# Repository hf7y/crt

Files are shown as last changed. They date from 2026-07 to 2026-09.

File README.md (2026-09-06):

# crt

Landline handset + CRT monitor as a voice-driven front end for Claude Code,
autobooting on potato, a Raspberry Pi.

## Signal path

```
handset mic (TRRS) --> potato audio in --> whisper (dexter's container, VAD-segmented)
                                                    |
                                                    v
                                        tmux send-keys into `claude` pane
                                                    |
                                                    v
                                          Claude Code CLI on CRT (HDMI->RCA)

hookswitch (mechanical, printed) --> USB keyboard-encoder --> evdev listener
                                                                     |
                                              pause/resume the STT loop
```

## One-time setup (on the console)

```
./install.sh
sudo reboot
```

This installs whisper.cpp + a base.en model, Claude Code CLI, and configures
tty1 to auto-login and drop straight into `bin/crt-console.sh`, which opens a
tmux session: Claude Code in the main pane, `stt-feed.sh` listening in a
lower pane. After reboot, no keyboard interaction is needed to reach the
Claude Code prompt.

First boot: `claude` will need a one-time interactive login (network
required). Do that once before relying on unattended autoboot.

## Manual test (no reboot)

```
bash bin/crt-console.sh
```

## Audio capture troubleshooting

Getting the mic to work took several non-obvious fixes; if a fresh deploy
captures silence, check these in order:

1. **User must be in the `audio` group.** Without a desktop/logind seat (i.e.
   over SSH, or on a stripped console-only box), `/dev/snd/*` is only reachable
   via the `audio` group. `install.sh` adds the user; a re-login/reboot applies
   it. Symptom: `arecord -l` says "no soundcards found" though the kernel shows
   the card in `/proc/asound/cards`.

2. **Capture from the hardware device, not ALSA `default`.** `default` can be
   silently re-routed to a dead PulseAudio/PipeWire by leftover config
   drop-ins. `stt-feed.sh` uses `plughw:0,0` via `CRT_AUDIO_DEV` for this reason.

3. **VAD threshold.** A quiet capture path (speech RMS ~1%) never trips the
   default 3% silence gate; lower it with
   `CRT_VAD_THRESHOLD`. Symptom: `rec` runs forever
   on `utt_1` and never emits a `[stt-feed] ->` line. Verify capture works at
   all by recording directly and transcribing:
   ```
   arecord -D plughw:0,0 -f S16_LE -c1 -r16000 -d 5 /tmp/t.wav
   ~/whisper.cpp/build/bin/whisper-cli -m ~/whisper.cpp/models/ggml-base.en.bin -f /tmp/t.wav -nt -np
   ```

## Hookswitch (physical on/off)

The mechanical hookswitch is **not wired to any analog phone line** — no PBX,
so no relay. It's a plain logic-level contact, read via `CRT_HOOK_TRANSPORT`
(`evtest`, default, or `gpio`):

**`evtest`.** Wire the microswitch (via `cad/switch_mount.scad`) to a cheap
USB arcade-button/keyboard-encoder board, one key while closed.
```
evtest                       # find the encoder's device path and confirm the key it sends
export CRT_HOOK_DEVICE=/dev/input/by-id/usb-...-event-kbd
export CRT_HOOK_KEY=KEY_F13  # match whatever the encoder actually sends
```

**`gpio`.** Wire the switch straight to a Pi GPIO pin instead (HOOKSWITCH.md option 3):
```
export CRT_HOOK_TRANSPORT=gpio
export CRT_HOOK_GPIO_PIN=17          # BCM pin the switch is wired to
export CRT_HOOK_GPIO_ACTIVE_LOW=1    # 1: pull-up, switch-to-GND on-hook (default)
```

Add the exports to `.bash_profile` above the `crt autoboot` block (installer
leaves a marker). Autostart then opens a third pane running
`hookswitch-listen.sh`, which SIGSTOPs/SIGCONTs `stt-feed.sh` as the handset
is placed down / picked up.

## 3D-printed handset assembly (`cad/`)

Four parametric OpenSCAD parts, one assembly:

- `phone_saddle.scad` — cup the handset barrel rests in ("phone" contact piece)
- `hook_lever.scad` — see-saw lever; handset weight presses it onto the switch
- `switch_mount.scad` — bracket holding the microswitch under the lever
- `cradle.scad` — base body with pivot-pin bosses and switch mount pocket

**Edit `cad/params.scad` first** — measure your actual handset barrel
diameter and your microswitch's real dimensions/hole spacing; the shipped
values are generic placeholders, not measurements of your hardware.

Render all STLs:
```
./cad/export_stl.sh
```
Outputs to `cad/stl/`. Assemble with a steel pin/M4 bolt through the pivot
bosses, then screw the switch into `switch_mount.scad` and tune
`switch_mount_h` in `params.scad` until the lever fully depresses the
plunger only when the handset is resting (not lifted).

## Bare-metal deployment (e.g. Intel Compute Stick)

Everything in `bin/` and `install.sh` targets any Debian/Ubuntu machine, and
the console settled on a Raspberry Pi (potato) rather than a hypervisor guest.

**Confirmed target (2026-07-21): Debian 13.6, amd64.** `install.sh`'s
package list (`build-essential cmake git tmux sox alsa-utils curl
openscad evtest`) is all present in Debian 13's repos under those exact
names — nothing to substitute. If the actual stick's CPU turns out to be
more capable than a Celeron (amd64 covers a wide range), test `base.en`
before defaulting to `tiny.en` below; the tradeoff is real either way,
this isn't a hard requirement, just the safe assumption for the weakest
hardware this doc originally targeted.

**Barcode scanner needs no forwarding at all on a single-box deployment**
(2026-07-21, see `SCANNER.md`'s "compute-stick prep" section) — the whole
`dexter-scanner-forward.ps1` / NAT-forward / `crt-scanner-feed.py`-HTTP
bridge exists only because the VM path splits the scanner (on Windows)
from the console (in the guest). Bare metal has one machine: plug the
USB scanner directly into the stick, and `crt-book-console.py`'s stdin
path (already the primary scan path, `install.sh` wires nothing extra
for it) picks it up with zero network hop.

Differences from the VM path:

- **Whisper model**: `base.en` is too heavy for a Celeron in real time.
  Use the smaller/faster `tiny.en` instead:
  ```
  CRT_WHISPER_MODEL_NAME=tiny.en ./install.sh
  ```
  (`install.sh` downloads whichever model name you pass and wires
  `CRT_WHISPER_MODEL` automatically if it isn't the default `base.en`.)
  Expect a noticeable accuracy drop vs `base.en` — worth testing both if
  the stick can keep up with `base.en` at all before committing to `tiny.en`.
- **Audio input**: most compute sticks expose only HDMI audio out (or a
  single combo headphone/mic jack, sometimes output-only). Check
  `arecord -l` after boot — if there's no capture device, or capture is a
  garbled combo-jack signal, add a cheap USB audio adapter for the TRRS
  handset mic rather than relying on onboard audio in.
- **Video out**: HDMI is typically native on these sticks, so the same
  HDMI→RCA path to the CRT applies unchanged.
- **Everything else** (autologin, tmux wiring, hookswitch evdev listener,
  `crt-console.sh`) is identical — `install.sh` + reboot is the whole setup.
- **Finding it on the network** (2026-07-21): `install.sh` installs
  `avahi-daemon` and sets the hostname (`CRT_HOSTNAME`, default
  `crt-console`), so it's reachable as `crt-console.local` from any
  device on the same LAN segment — no static IP, no router config
  (mDNS/multicast, same mechanism that makes `dexter.local` work).
  Doesn't cross routers/VLANs, though — `crt-console.sh` also flashes
  the box's actual IP on the physical screen for a few seconds at boot
  (`CRT_IP_FLASH_SECS`, default 4, `0` to disable) as a fallback that
  works regardless of network topology.
- **First-boot setup, unattended**: `install.sh` now supports both
  editing its own `CONFIG` block at the top (WiFi SSID/password,
  hostname, Gemini key, Claude credentials path) and answering
  interactive prompts for the same values — including pasting a
  `.credentials.json` directly at the prompt to skip Claude Code's
  one-time login entirely. See that file's own header.

## Porting to native Windows later

The STT/tmux/Claude Code pieces (`bin/`) are Linux-specific (evdev, ALSA,
tmux). Porting means: swap `sox`/`rec` for a Windows-native audio capture,
swap `evtest`/evdev for a Windows raw-HID or keyboard-hook listener for the
hookswitch encoder, and replace tmux + autologin with a Windows Task
Scheduler entry running at logon that opens a terminal into the same
`claude` + STT-feed pair. The whisper.cpp binary and model are portable
as-is (Windows build exists upstream).

## Why this repo is public

Decided 2026-09-05 (hf7y/crt#148): public keeps Actions free for the images
dexter runs, and exposes topology only, never access. The `gitleaks` PR
check is what keeps that true by construction, not by care.

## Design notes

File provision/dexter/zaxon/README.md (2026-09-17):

# zaxon — crt's WhatsApp channel

**crt owns zaxon as of 2026-08-14 (Zach's call.)** An MCP server over
streamable-http exposing `ask_zach`, `revise_zach_question` and
`check_zach_reply`; loopback and tailnet only (#52). See `compose.yaml` for the
rest. One question per ticket, enforced at the send (crt#190) -- see the
`instructions=` string in `relay/zaxon_relay_server.py`.

Deploys are automatic — `srv-reconcile` (senechal-owned, dexter-wide, crt#322)
pulls and verifies `/srv/zaxon` on its own timer, rolling back on failure.
`zaxon-autoupdate.timer` did this job until crt#334 retired it, once
srv-reconcile covered zaxon too and running both risked a race. By hand:
`sudo docker compose pull && sudo docker compose up -d` (`sudo` because
`zach` is not in the `docker` group).

`data/` is service state, never overwritten from a repo; the relay's SOURCE ships in the image.

## The status page

`hf7y.com/zaxon` — `zaxon-watch.sh --apply` hourly, `--install` writes the timer,
`--check` publishes nothing. What used to be written down here as rules a reader
had to remember is enforced by `tests/test_zaxon_watch_guards.sh` and reported
by the page itself: the one-holder rule for `data/whatsapp/session` and
`data/auth.json` (crt#193, crt#195), the never-bind-`0.0.0.0` rule, where the
STT command lives, and why a relay that merely answers is never `OK`.

## Open

- `hermes` is still registered and can still seize the session (page reports it hourly); before `wsl --unregister hermes`, its verified `.vhdx`/`ggml-base.en.bin` export is at `/mnt/d/gardien-backups/hermes-wsl-export/` on dexter.
- **Opt-in shared-secret auth landed (crt#194)** — `relay/zaxon_relay_server.py`
  refuses any request missing the right `X-Zaxon-Shared-Secret` header once
  `ZAXON_SHARED_SECRET` is set, but ships unconfigured (a no-op, same as
  before) until dexter's own `provision/dexter/zaxon/.env` sets it. Still
  unauthenticated on the tailnet until that step happens.
- Stop the old stack before starting a new one against this same `data/`: two stacks holding one
  Nous refresh token revoked the session for 8 days (crt#193, 2026-08-30's migration overlap).

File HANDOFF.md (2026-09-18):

# crt — current state & handoff

Voice-driven secretary console: a landline handset + CRT TV as the human
interface. This doc is the pick-up-where-we-left-off summary — read this
first, then follow the pointers below for depth on any one piece.

**Read next, depending on what you're doing:**
- `README.md` — the how-and-why of each original piece, incl. detailed audio
  troubleshooting.
- `gh issue list -R hf7y/crt` — current backlog/status; the file backlog is retired.
- `SECRETARY.md` — the actual product vision (phone secretary, not a raw STT
  terminal) and what's built vs. still design-only.
- `AUDIO-DEBUG.md` — mic capture staleness debugging (5 parallel approaches).
- `vault:crt/AUDIO-ROUTING.md` — TV vs. phone-earpiece audio output separation.
- `vault:crt/PARKING-LOT.md` — the deep end-state vision (RF power-on, hidden
  transcription, predictive-text feel, morning-reports + media-playback as
  the two core jobs). Not built, captured so it isn't lost.
- `SCANNER.md` — USB 1D barcode scanner, forwarded into the console's tmux
  pane. Read this before `BOOK-GAME.md`'s scanner-passthrough note.
- `BOOK-GAME.md` — barcode-scan book trivia game, standalone build, doubles
  as structured STT training-data collection and a personal library
  registry.
- `POTATO.md` — the live console hardware (a Raspberry Pi).

## Current topology (2026-08-29)

`potato` (a Raspberry Pi) is the live console — real ALSA hardware, no VM.
`dexter` now hosts the **Zaxon** relay (`provision/dexter/zaxon/`),
reachable over tailscale — not the Windows+VirtualBox `crt-vm` host this
file used to describe. That earlier topology (2026-07-19 through
2026-07-21: dexter as a Windows 11 + VirtualBox host, mandark as the
manual deploy hop, the tmux window layout that ran on `crt-vm`) is archived
byte-for-byte at `vault:crt/HANDOFF-20260829.md` for anyone digging into
that era's history — none of it describes what's running today.

### potato's SSH host keys (recorded 2026-09-18)

    ED25519  SHA256:mrixOpBAg+5Dw9RDosa2Y/5TRwrlCuS3i6GB0NB3JLs
    ECDSA    SHA256:w+XhU6NJJsHQsUQXw613GDUtECBnzzFn30ctj6GWLVI
    RSA      SHA256:gJ19h5hZm63NsgvRhKTawGF1OfqNsXvEsDxKiUgPqqM

Here because they were **nowhere in this tree**, and that is what stalled
crt#342: monkey's `ssh potato` now resolves and connects over tailscale, and
stops at host-key verification with nothing to check the fingerprint against.
A first connection with no recorded fingerprint is trust-on-first-use against
whoever answers, which is not a thing to do blind on a box that holds a
deploy key.

Read off `/etc/ssh/ssh_host_*_key.pub` on potato itself over an already
authenticated session — not scanned from the network, which would prove
nothing a spoofer could not also arrange. The ED25519 line independently
matches mandark's own `known_hosts` entry from an earlier verified
connection, and matches the fingerprint crt#342 saw from monkey.

Reaching potato at all: prefer `ssh -i ~/.ssh/vkv_deploy_key
vkv@100.81.177.122` over the `Host potato` alias, which on mandark still
points at the pre-move LAN address and gets `No route to host` (see
`CLAUDE.md`, and crt#323 for the move itself).

Current state, blockers, and access gaps live in
`gh issue list -R hf7y/crt`, not in this file.

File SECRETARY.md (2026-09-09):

# crt as a phone secretary, not a raw Claude Code terminal

**Reframing (2026-07-19):** the ultimate goal isn't "STT typed into Claude
Code." It's a **secretary-like service** reached via the handset — Claude Code
is the backend brain, but the phone interaction should feel like talking to an
assistant, not dictating into a terminal. This file tracks that direction so
it isn't lost; not fully implemented yet, most of it is design + a couple of
supporting scripts (TTS, pager) that will be reused by whatever wrapper
eventually replaces the raw "type into Claude's pane" model.

## Output channels, by length/urgency
- **Printer (Phomemo M02, `bin/catprint`)** — the channel for anything long:
  job/report status, logs, anything you'd scroll through. Long text does NOT
  belong on the CRT.
- **CRT** — short status + interactivity only. If something longer genuinely
  needs to show there, it scrolls **slowly** rather than dumping — see
  `bin/crt-pager.py` (line-by-line auto-scroll, pause/resume/jump via the
  shared control file, jog-able once a MIDI knob is wired to it).
- **TTS through the phone earpiece** (`bin/crt-tts.py`, calibrated via
  `bin/crt-tts-calibrate.py`) — short spoken confirmations for the person on
  the handset. This is the "secretary" voice.
- **TTS through the TV** (`bin/crt-announce.sh`, rate-limited to 1/15min) —
  for getting **Chris's** attention when he's in the room but not on the
  phone. He can only respond by talking into the handset (no clicking/typing).
  See `vault:crt/AUDIO-ROUTING.md` for why this is likely a host (Windows), not guest
  (VM), problem, and the current state of that bridge (not yet built).

## What a "secretary" interaction should feel like (not yet built)
Rather than every utterance being typed verbatim into Claude's terminal input
(today's model, still the working baseline), a secretary wrapper would:
1. Listen for a request ("what's my nightly build status", "tell Chris the
   report's ready", "read me the last thing that failed").
2. Hand it to Claude Code as a scoped, structured ask — not a raw keystroke
   feed — and get back a response.
3. **Speak** a short answer through the earpiece (crt-tts.py), and/or print a
   full report to the Phomemo, and/or scroll a longer answer on the CRT
   (crt-pager.py) if it must be read there.
4. Never assume the caller can read a screen — voice in, voice/print out,
   CRT only for short status glances.

## Current implementation status
- TTS engine + calibration: written, not yet audited by ear (`bin/crt-tts.py`,
  `bin/crt-tts-calibrate.py`). Deployed + smoke-tested (exit 0, no errors) on
  the pre-retirement VM console (crt#162) 2026-07-19 via `espeak-ng`.
- Speak-back debug loop (`bin/crt-stt-speakback.sh`): runs the STT engine in
  **debug mode (stdout only, NOT wired to Claude)** and speaks back
  "heard: ..." for each transcription — lets a person on the handset debug
  the mic/STT purely by ear. Running live on the pre-retirement VM's `stt` tmux window as of
  2026-07-19 14:40 (replaced the old stt-feed.sh+crt-levels.sh pipeline for
  this debug session — restore with `crt-console.sh` for the normal
  Claude-wired flow).
- Pager (`bin/crt-pager.py`): written, syntax-tested with synthetic text
  (wraps to 40 cols, scrolls, footer shows page%/END). Not yet wired to any
  real Claude output or a MIDI knob.
- The secretary wrapper (steps 1-4 above) is `bin/crt-secretary.py`
  (2026-07-19) — the playbook-vs-Claude routing and local-answer detail
  now live in `SUPERVISOR.md`, not duplicated here. **Wired into both live
  entry points, opt-in and default off in each:** `stt-feed.sh`'s
  `CRT_SECRETARY` flag (`tests/test_stt_feed_secretary_flag.sh`) and
  `crt-stt-solo.py`'s `SINK=secretary` mode
  (`tests/test_stt_secretary_sink.py`). Neither opt-in has been flipped on
  and watched live yet — the Claude-routing path's idle-detection (poll
  `capture_pane()` until unchanged for N seconds) is still an untested
  heuristic, the riskiest part of this design.

## The three outcomes of a Claude escalation, and why they are three (2026-07-25)

Once Claude Code moved off potato onto mandark behind a reverse tunnel, an
escalation stopped having two possible endings and started having three.
They were collapsed into one spoken line for a while, in both directions,
and each collapse was a separate bug:

| outcome | what actually happened | the line |
|---|---|---|
| **answered** | it landed, a reply was read | the reply itself |
| **never sent** | the tunnel/bridge was down, or tmux refused the keys | `BRAIN_UNREACHABLE_LINE` — "I can't reach my brain right now, so that didn't go anywhere" |
| **sent, reply unobserved** | it landed; `capture_pane()` couldn't be read afterwards | `REPLY_UNOBSERVED_LINE` — "I sent that to Claude, but I lost my view of the answer partway through" |

The rule this encodes: **the console may only report what it observed.**
"I sent that to Claude but didn't catch a reply — check the screen" is
reserved for the one case where all three of its claims are true — it was
sent, a reply was genuinely watched for, and the screen has whatever came.
Using it for the other two was wrong twice each: nothing was sent, or
nothing was watched.

Mechanically, this rests on `capture_pane()` returning `None` (unreadable)
rather than `""` (read, empty). Anything that collapses those two again
re-opens both bugs — the second one loudly: with no baseline to diff
against, every line on the pane counts as new, so 200 lines of scrollback
get spoken into the earpiece and printed on the Phomemo. Covered by
`tests/test_secretary.py`'s `TestUnobservedReply`, which injects at the
bridge socket rather than stubbing `capture_pane()`, because stubbing it
reproduces neither failure.

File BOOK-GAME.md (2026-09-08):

# Book Game: a training-data game (vision 2026-07-21, shipped same day, running on `potato`)

See `BOOK-GAME-STYLE.md` for personality/animation/screen-layout/color and
`SCANNER.md` for how a scan physically reaches this game.

## Why this exists

The console needs a way to collect **structured** speech samples — known
expected text, known actual transcription — cheaply and continuously. This
game's mechanic *is* that: "say this specific word/phrase, we already know
what you should be saying." It's byproduct-first — playable on its own, and
every round also produces a labeled (expected, heard) pair.

## The loop

Scan a book's ISBN (USB HID scanner, no driver) → look up title/author/facts
(Open Library/Google Books, cached) → ask a 2-option question about the book
→ listen for the spoken answer via the existing mic pipeline → grade it
exact-ish (normalize, don't fuzzy-match) → register the book (ISBN, facts,
this round's result) into a local SQLite catalog, independent of the game
itself ("my library" via `crt-book-catalog.py` / `crt-secretary.py`).

Grading tracks two axes, not one: `correct_content` (did they know the book
fact) and `correct_stt` (did the mic hear an option that was on offer,
`null` if no option list was recorded). They can disagree — a right-content,
wrong-STT round is the valuable training case. See `grade_answer()`'s
docstring in `bin/crt-book-game.py` for exactly how `correct_stt` is judged.

Question generation mixes deterministic templates with batched,
cached Claude-authored questions (~50/50, batched per-scan-burst rather than
one live call per book) — see `build_claude_batch_prompt()`/
`parse_claude_batch_response()` in `bin/crt-book-game.py`.

## Scanner delivery: two paths, one of them a live finding

`SCANNER.md`'s dexter-bridge (network, `[scan] <isbn>` into tmux) is one
path. The one actually used in practice is simpler: the scanner is HID
keyboard input ending in Enter, and raw scan keystrokes reach **whichever
tmux window currently has focus**, not a specific one — `crt-book-console.py`
reads stdin directly rather than needing to be targeted.

## What's live now

Built and running on `potato`, standalone-first then wired into
`crt-console.sh`'s `book`/`bookanswer` windows:

- `bin/crt-book-game.py` — lookup, question generation, grading, SQLite
  registry, best-effort LCC. `tests/test_book_game.py`,
  `tests/test_book_game_stt_axis.py`.
- `bin/crt-book-console.py` — the `book` tmux window: tails the scanner log,
  renders the question screen. `tests/test_book_console.py`.
- `bin/crt-book-answer-listen.py` — the `bookanswer` window: watches
  `~/.crt/stt.log` and grades the next utterance automatically, within
  `CRT_BOOK_ANSWER_WINDOW_SECS` of a scan.
- `bin/crt-book-catalog.py` — "my library" catalog view/playbook.
  `tests/test_book_catalog.py`.

**Resolved v1 decision:** no label printer. The LCC call number, when
computed, displays in the question screen's title line instead
(`crt-book-console.py`'s `render_scan_result()`) — revisit physical labels
only if Bluetooth-through-VM printing gets solved some other way.

**Not yet eye-verified on the real tube** — same caveat as
`BOOK-GAME-STYLE.md`'s own Status section.

## Open

`bin/crt-midi-knobs.py` is unrelated hardware still not verified on any
current host — its own header covers the how and current status.

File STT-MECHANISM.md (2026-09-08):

# How STT actually works here (read this if you're improving inference)

You (claude, running in this VM) receive text typed by a script, not
literally spoken to you — this is the real pipeline behind it, so you can
reason about *why* a given transcription got garbled the way it did.

## The pipeline
1. **Capture**: `bin/crt-stt-solo.py` is the sole mic reader (deliberately —
   two readers on the emulated capture device starve each other, see
   AUDIO-DEBUG.md). It reads a continuous raw PCM stream (16kHz mono S16) from
   one `arecord` it keeps open for the life of the process. The device is
   resolved by NAME from `arecord -l` (`CRT_AUDIO_DEV_NAME`, default "USB
   Audio") with `CRT_AUDIO_DEV` as a hard override — potato pins
   `plughw:1,0`. (Older notes here said `crtmic`, a dsnoop wrapper; that was
   the pre-retirement VM era (crt#162) and is gone.)

   **Capture pauses while whisper runs, and that is where follow-ups go to
   die.** Step 4 happens *inside* this same loop, so for the 1–3s a
   transcription takes, nobody is reading `arecord`. What arrives meanwhile
   sits in the kernel pipe, which held 2.05 seconds of audio by default —
   less than a transcription takes, after which the audio was simply lost,
   invisibly. Since 2026-07-25 the pipe is widened to
   `CRT_CAPTURE_PIPE_BYTES` (256 KiB ≈ 8.2s) and the startup line prints the
   real depth in seconds. So: **an utterance spoken in the second or two
   right after another one may have no audio at all behind it** — if a
   follow-up seems to have been ignored rather than misheard, this is a
   likelier cause than the wake gate, and it predates every gate/arm-window
   change made for that symptom.

   Whatever queued during that pause is also *old* by the time it is read, so
   anything older than `CRT_CAPTURE_BACKLOG_MAX_SECS` (3s) is dropped —
   newest audio kept — and the pane says `dropped N.Ns of backlogged audio`
   when it happens. If you are reconstructing a session from `stt.log` and a
   gap does not line up with a silence, check the pane for that line.
2. **VAD (voice activity detection)**: peak-based, not RMS/average — checked
   every 100ms chunk. Speech starts once peak crosses `CRT_VAD_THRESHOLD`
   (percent of full scale) for a couple consecutive chunks, and ends after
   `CRT_VAD_TRAIL` seconds below threshold. This means: **very quiet speech,
   or speech with a soft/trailing consonant, can get its tail clipped early**
   if it dips below threshold mid-word. A word cut short is a likely
   explanation for some garbling, not just whisper mishearing.

   **The capture duck can also punch a hole in an utterance.** While the
   handset is playing something (a TTS reply, an earcon), capture is "ducked"
   via the control file, and those chunks are *dropped from the buffer* — the
   silence timer freezes, and speech either side of the duck is spliced
   together (`utt_chunk()` in `crt-stt-solo.py`; before 2026-07-25 the
   console's own playback was buffered into the sentence instead, which is
   worse). So a second explanation for a mangled word: the console started
   talking over the speaker, and the word straddling that moment lost its
   middle. If the duck outlasts `CRT_MUTE_UTT_MAX_SECS` (2s) the utterance is
   closed and transcribed as-is, so a long reply can also cut a sentence in
   half rather than clipping a word.

   The same applies to the **pre-roll** — the `CRT_VAD_PREROLL` chunks kept
   before onset so a first word's soft attack isn't lost. Ducked chunks are
   kept out of it as well (2026-07-25), so an utterance that begins right
   after the console stops talking opens on the room tone from before the
   playback, not on the playback's own tail. Before that fix, a follow-up
   spoken straight after the `addressed` earcon was handed to whisper with
   up to `CRT_VAD_PREROLL`×100ms of that earcon in front of it — worth
   knowing if you're reading older `stt.log` entries where a follow-up
   picked up a phantom leading word.
3. **Denoise** (optional, currently on): a sox chain — highpass filter, then
   `noisered` against a captured noise profile (`~/crt/noise.prof`, built
   from a sample of the room's AC hum), then peak normalize. This tames
   AC-hum-induced hallucinations but **can also subtly distort speech
   spectral content**, especially sibilants (s/sh/f sounds) and other
   high-frequency consonants — if you notice a pattern of dropped/garbled
   consonants specifically at the start or end of words, this filter chain
   is a likely contributor, not just whisper itself.
4. **Transcription**: either local `whisper.cpp` (`base.en`) on the console
   itself, or (when `CRT_WHISPER_SERVER` is set — potato's boot default,
   `crt-console.sh`) a POST to `whisper.cpp`'s own `whisper-server`,
   containerized on dexter (`provision/dexter/whisper/`) — same model
   family either way. The mandark-hosted `faster-whisper` predecessor this
   used to describe was retired (crt#149); CLI flags like `-bs`/`--beam-size`
   are a real lever now, passed via `provision/dexter/zaxon/compose.yaml`.

   **A failure here is not a silence, and since 2026-07-25 it no longer
   pretends to be one.** `transcribe_remote()` returns `None` when it could
   not get an answer out of the server at all (unreachable, timeout, HTTP
   error, unparseable body) and `""` only when the server genuinely heard
   nothing. Before that it returned `""` for both, so an unreachable mandark
   made the console go completely silent with nothing anywhere saying why —
   if you are reading `stt.log` from before this date and a stretch of a
   session is simply *missing*, a dead whisper server is a live candidate,
   not just a quiet room. Now: `! stt lost it` flashes on the tube every time
   it happens, and the pane carries a `TRANSCRIPTION FAILED` line on the
   first failure of a run and every tenth after it, plus one when it
   recovers. A failed call falls back to the local `whisper.cpp` build on this
   box, if one is present (`CRT_WHISPER_LOCAL_FALLBACK=0` disables it; crt#132).
5. **Filtering before it reaches you**: a hardcoded set of whisper's known
   noise-hallucination outputs get dropped entirely (`HALLU` in
   `crt-stt-solo.py` — things like "thank you", "music playing"), as does
   any output that's fully bracket/symbol-wrapped ("(metal clanging)"). If
   you see something clearly garbled make it through, it wasn't caught by
   this filter — worth suggesting an addition if a pattern recurs.
6. **Delivery to you**: the raw text is typed into your input via
   `tmux send-keys`, one utterance per line, immediately after step 5 — you
   are seeing whisper's raw output (post-filter), not a human-cleaned
   version. Single-word utterances matching a small fixed vocabulary
   ("yes"/"no"/"enter"/"up"/"down"/etc., see `CONTROL` in `crt-stt-solo.py`)
   get converted to keystrokes instead of typed text — if you ever see an
   unexpected keystroke effect instead of text, that's why.

## What this means for improving inference
- A "garbled" transcription could be: (a) whisper genuinely mishearing, (b)
  the denoise filter distorting a consonant, (c) VAD clipping the start/end
  of the utterance, or (d) the noise floor itself (AC hum) bleeding through.
  These have different signatures — (c) tends to lose whole syllables at
  utterance boundaries specifically; (b) tends to lose/soften sibilants
  anywhere; (a) tends to substitute a whole different (but phonetically
  similar) word or homophone.
- A *missing* transcription is a different question from a garbled one, and
  it has its own three causes, all documented above: the wake gate dropped it
  (nothing wrong with the audio), capture was busy transcribing the previous
  utterance (step 1), or the recogniser itself failed (step 4). Only the
  first is about what was said. Check the pane before assuming the mic or the
  room is at fault.
- `~/.crt/stt.log` has every raw utterance, unfiltered by your own judgment —
  useful for spotting a recurring pattern across many utterances rather than
  reasoning from just the one in front of you.
- If you find a config-level fix (raise `CRT_VAD_TRAIL`, adjust denoise
  strength, etc.) rather than just a learned correction pattern, that's a
  more durable fix — feel free to propose or make such a change (it's your
  own project), just note what you changed and why in your thoughts log.

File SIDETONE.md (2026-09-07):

# Sidetone

## What it is
On a real telephone, "sidetone" is a small deliberate leak of your own
mic signal back into your own earpiece, so the line doesn't feel dead.
Two effects that matter to us specifically:
1. **Confidence the line is live** — without it, people (subconsciously)
   assume the mic isn't working and either repeat themselves or raise
   their voice.
2. **Natural volume self-regulation** — hearing yourself lets you match
   your voice to the room without thinking about it. Too little sidetone
   and people shout; too much and they whisper. Real phone engineering
   targets a specific *loss* (sidetone is deliberately quieter than your
   real voice, not 1:1) for exactly this reason.

## Why this is an STT-accuracy lever, not just a nice-to-have
Per `CLAUDE.md`, improving STT inference is this console's top priority,
and per `STT-MECHANISM.md`, a chunk of garbling here is plausibly
**VAD clipping quiet speech** and **denoise distorting sibilants** — both
of which get *worse* the quieter/more hesitant someone talks. A noisy
room with no sidetone is exactly the condition that produces the
worst-case input for this pipeline: someone unsure if they're being heard,
talking too quietly (VAD/denoise struggle) or too loud (clipping,
distortion). Sidetone isn't cosmetic here — it's upstream of the actual
transcription-quality problem this project is already trying to solve.

## The complication: where does the handset earpiece actually live?
`vault:crt/AUDIO-ROUTING.md` (written before the dexter bridge existed) assumed the
handset earpiece stays a **guest-local** ALSA device while only the TV
output moves to the host. But `bin/crt-tts.py`'s current `DEXTER_DEVICES`
tuple is `("tv", "handset")` — **both** now route through
`dexter-audio-server.py` over HTTP. That's fine for short TTS clips (a
network POST per phrase is imperceptible), but it's fatal for sidetone,
which needs near-zero latency (a few ms) to feel like your own voice
rather than a laggy echo. A round-trip through dexter would be the worst
possible way to implement this.

**Resolved 2026-07-21** (see that date's entry under Status, below): the
handset is only reachable via dexter's host-side bridge, not a guest-local
device, so option 2 below (guest-local loopback) isn't viable. `crt-vm`,
the guest named in that original question, no longer exists (`hf7y/crt#162`).

## Recommended approach, in priority order

### 1. Passive hardware sidetone (best: zero latency, zero software)
This is how real phones have always done it — a resistor or small
transformer tap between the mic and earpiece wires, physically upstream
of any USB/VM boundary. If the handset's mic and earpiece are wired
through a simple audio interface (not yet designed — see the hookswitch/
cad work), adding a passive tap here is cheap (~$1 of parts) and has
**zero** latency because it never touches software at all. This is the
right answer if the handset's electrical path is still being designed
(it is — see `cad/` for the mechanical side, no audio wiring plan exists
yet). Worth deciding the mic/earpiece wiring **with sidetone in mind from
the start** rather than retrofitting later.

### 2. Local-only software loopback (superseded 2026-07-21 -- see Status)
As originally written this assumed a guest-local device (`crt-vm`); the
question above resolved the other way, so this exact form is dead. Carried
forward host-side instead (Status, below) -- same idea, moved to dexter. A
persistent low-level passthrough, never touching the network:
- Cheapest form: a standing `sox -t alsa crtmic -t alsa <earpiece-dev>
  vol 0.15` pipe (or equivalent `arecord | sox ... | aplay` chain),
  started alongside `crt-stt-solo.py`.
- Since `crt-stt-solo.py` already owns the sole mic reader (see
  AUDIO-DEBUG.md — two readers starve each other), sidetone should tap
  the **same** stream it already reads rather than opening a second ALSA
  capture handle. Practically: a low-volume raw (pre-denoise, to keep
  latency minimal — denoise is not free) write-through to the earpiece
  device inside its existing read loop.
- **Must duck automatically** whenever TTS or an earcon is about to play
  on the same device, or the two will fight over a single ALSA sink (and
  briefly, sidetone-of-the-TTS-itself would be an unpleasant echo). A
  simple mute flag set for the duration of `crt-tts.py`/`crt-earcon.sh`
  calls is enough; exact mechanism TBD once device ownership (see above)
  is settled.
- Volume: start around **10-15%** (matches real telephone engineering's
  "quieter than your real voice" target) — pure guess, needs a human ear
  to tune, same caveat as `crt-tts-calibrate.py`.

### 3. Not recommended: routing sidetone through the dexter bridge
Explicitly ruled out above (latency). Noted only so a future session
doesn't reinvent it and rediscover the same problem.

## Status
Design only — nothing built.

**2026-07-21 (Chris): software sidetone, handled dexter-side.** Resolves
the tension flagged earlier the same day: since the handset is only
reachable via dexter (`.claude/QUESTIONS.md`, 2026-07-20), sidetone runs
as a loop **local to dexter itself** — mic-in to earpiece-out entirely on
the host, never crossing into the VM. This sidesteps the original
objection to "routing through the dexter bridge" (option 3 above), which
was about the VM round-trip specifically (`crt-vm` asking dexter over
HTTP per phrase); a same-machine host-side loop has none of that latency
since it never leaves dexter. Supersedes option 2 above (guest-local
loopback) — not viable per the routing answer, so this is the new
option 2, not option 1's passive-hardware tap. Next concrete step:
design the dexter-side loop (equivalent to option 2's `sox`/`arecord|sox|
aplay` pipe, but as a persistent process on dexter, wired into whatever
already owns dexter's audio I/O for this project — see
`dexter-audio-server.py`/`dexter-whisper-server.py`) — needs the same
duck-around-TTS and volume-tuning treatment already described above.

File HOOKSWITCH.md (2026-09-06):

# Hookswitch: behavior spec

The physical embodiment of `PHILOSOPHY.md` #4 (verbs, not menus) — per
`PARKING-LOT.md`, this is the **primary** interface hardware, ahead of the
CRT or any knob. Formalizing the intended behavior here so
`bin/hookswitch-listen.sh` has a spec to be checked against, not just
whatever the first draft happened to do.

## States
- **On-hook** (handset resting, switch closed): STT paused. This is the
  console's resting state — inert, not listening, matching
  `PARKING-LOT.md`'s RF-power-on vision where resting = actually off/idle,
  not silently-still-recording standby.
- **Off-hook** (handset lifted, switch open): STT active, listening.
- **Transition (bounce)**: a mechanical switch does not move cleanly
  between states — it chatters for a few milliseconds. Untreated, this
  looks like a rapid sequence of on/off events to software.

## The bug this session found (no hardware needed to find it)
`hookswitch-listen.sh` currently maps the encoder's raw key-value events
straight to `pkill -STOP`/`pkill -CONT` with **no debounce**. A single
physical pickup/hangup can plausibly emit several bounced transitions
within a few milliseconds — each one now fires a real STOP/CONT signal at
`stt-feed.sh`. Best case this is just wasted signals; worst case a STOP
lands after the matching CONT (reordered by process scheduling) and the
STT process ends up stopped when the handset is actually off-hook, i.e.
**the console silently stops listening while looking like it's on**. This
is a genuine correctness bug reachable and fixable without any hardware —
software debounce is pure logic.

## Fix: debounce
Only act on a transition once the new state has held steady for a short
window (`CRT_HOOK_DEBOUNCE_MS`, default 50ms — mechanical switch bounce
is typically single-digit milliseconds, 50ms leaves comfortable margin
without adding perceptible lag to a real pickup). Implementation: track
the last-applied state and a pending-since timestamp; only call
`pkill -STOP`/`-CONT` when the raw signal has been consistent for the
full debounce window, collapsing any bounce train into exactly one action.

## Future states (not built, no hardware to build against yet)
- **Long off-hook, no speech** (idle timeout while lifted) — should this
  eventually re-mute STT and treat it like on-hook again, or stay
  listening indefinitely? Real question, no answer yet — flagging so it's
  not silently decided by whatever `crt-stt-solo.py`'s VAD timeout happens
  to do.
- **Quick on-hook/off-hook/on-hook** ("hang up, immediately pick back up")
  — is this a meaningful gesture (e.g. "never mind, restart") or just
  noise? Real telephones don't assign it meaning either; probably fine to
  leave unassigned, noting it here so it's a decision, not an oversight.
- **Persona-channel knob interaction** (`vault:crt/PERSONA-CHANNEL.md`) — the
  hookswitch and the channel knob are two independent physical inputs;
  worth deciding whether turning the channel knob while on-hook should do
  anything (probably not — picking up is still the actual "begin"
  gesture) versus off-hook (switching persona mid-call).

## Status
Debounce logic added to `hookswitch-listen.sh` this session (2026-07-19),
covered by a synthetic bounce-sequence test in `tests/`. Everything else
above is unbuilt/unverified — no physical switch to test bounce timing
against in reality, 50ms is a reasoned guess, not a measurement.

**2026-09-06:** option 3's software half (`CRT_HOOK_TRANSPORT=gpio`) is built and
tested against a fake sysfs tree; real wiring and option 1's hard-kill remain hardware-only.

## Wiring/kill options for the physical switch (design writeup, 2026-07-24)

Filed originally in scheduler's `BLOCKERS.md` as "the handset's 3-pin
switch" once `cad/HANDSET-MEASUREMENTS.md`'s handset part was confirmed
function-complete; routed here after a process correction (BLOCKERS.md
is human-only blockers, not a work queue this project's batch reads —
see that file's own crt entry). **Confirmed same mechanism, not a
distinct one**: `cad/params.scad`'s "Microswitch (measured: 3-pin lever
subminiature microswitch)" block and `cad/switch_mount.scad` ("bracket
holding a mini SPST/SPDT microswitch") are the switch `hook_lever.scad`
presses and `bin/hookswitch-listen.sh` already reads — this doc is that
switch's software/hardware wiring question, not a second hookswitch.

A 3-pin lever microswitch is a single-pole double-throw (SPDT): one COM
pin, plus NO (normally-open) and NC (normally-closed) pins relative to
the lever's rest position. Which pole gets wired, and what it's wired
*to*, is the actual decision — three real options:

**1. Hard-kill audio (electrical cut in the analog/USB audio path).**
Wire the switch inline with the handset mic's power or signal line
itself (e.g. cutting the USB audio interface's mic-in conductor, or a
relay/analog switch gated by the mechanical switch) so on-hook
physically silences capture with no software involved.
- Makes possible: the strongest privacy guarantee in the whole project —
  on-hook means the mic is physically incapable of picking up audio, not
  just "software chose not to record it." Directly matches
  `HOOKSWITCH.md`'s own on-hook framing ("resting = actually off/idle,
  not silently-still-recording standby") at the hardware level instead
  of trusting a process.
- Costs: needs real analog work (identifying which conductor to cut on
  the specific USB audio interface in use, possibly adding a small relay
  or FET switch and its own power), is the least reversible/most fiddly
  to prototype, and gives no soft states — there's no way to build the
  "future states" HOOKSWITCH.md already flags (long-off-hook idle
  timeout, quick-cycle gesture) on top of a hard electrical cut, since
  software never sees the transition at all past the initial event.

**2. Software mute on switch-close (extends the existing path).**
`bin/hookswitch-listen.sh` already does a version of this today — the
switch is wired to a cheap USB HID encoder board (logic-level signal,
not a load), and on-hook sends `pkill -STOP` to `stt-feed.sh` /
off-hook sends `-CONT`, with the debounce logic above. This option is
"keep that architecture," just naming it explicitly as a chosen
destination rather than a placeholder.
- Makes possible: everything already built stays valid (debounce test,
  `apply_state()`/`debounce_loop()` split for testability) with zero new
  hardware. It's also the only option that can cleanly grow into the
  "Future states" section above (idle-timeout re-mute, gesture handling)
  since software already sees every transition, not just an on/off edge.
- Costs: on-hook silence is a promise from a running process, not a
  physical fact — a hung/crashed `hookswitch-listen.sh`, or a race with
  `stt-feed.sh` restarting, could leave capture running while the
  handset looks safely hung up. This is exactly the class of bug
  `HOOKSWITCH.md`'s "bug this session found" section already found once
  (bounce reordering STOP-after-CONT) — software mute is provably
  correct only as far as its own test coverage reaches, not by
  construction.

**3. Pi GPIO signal into existing logic (bypass the USB HID encoder).**
Wire the switch's COM+NO (or NC) pins directly to two Pi GPIO pins
(one ground-referenced, with the Pi's internal pull-up/pull-down),
read the transition via `gpiozero`/`RPi.GPIO`/sysfs instead of an
`evtest`-parsed HID key stream, but keep the same debounce +
`apply_state()` shape.
- Makes possible: removes a whole hardware link (the USB HID encoder
  board) some cost/reliability, and unlocks reading the switch as a
  clean digital GPIO edge with the Pi's own hardware debounce
  primitives available as a second line of defense alongside the
  existing software debounce. Also opens the door to GPIO doing more
  than just this one switch later (e.g. the same board could host other
  buttons) without adding more USB HID hardware per input.
- Costs: swaps a `evtest`/HID-parsing bug class for a GPIO-wiring bug
  class (pull-up/pull-down direction, 3.3V logic level compatibility if
  the switch/board isn't already 3.3V-safe, physical wiring to header
  pins instead of a plug-and-play USB board) — real rework of
  `hookswitch-listen.sh`'s input layer, though `apply_state()`/
  `debounce_loop()`'s core logic and its existing test
  (`tests/test_hookswitch_debounce.sh`) can very likely be reused
  mostly as-is since they already operate on abstract "on"/"off" pending
  values, not HID-specific parsing.

**No recommendation made here on purpose** (Zach's call, same posture
`vault:crt/RFP-GALLERY.md`'s architecture writeup used) — options 2 and 3 are not
mutually exclusive with each other (3 is really "how option 2 gets its
raw signal"), while option 1 is a genuinely different, stronger-but-
costlier guarantee that could also be layered *underneath* either 2 or 3
later (hard-kill as a fail-safe, software mute as the primary/testable
path) rather than picked instead of them. No hardware access was needed
or used for this writeup — a live session is what's needed to actually
test switch-body pinout (COM/NO/NC continuity with a multimeter) before
any of these can be wired for real.

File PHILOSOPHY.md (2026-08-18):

# Philosophy

`PARKING-LOT.md` captured the first pass at this ("as close to nothing as
possible," blinking cursor, hidden transcription). This doc names the
underlying principles explicitly and pushes them further — the "why" behind
the parking lot, and behind `IDLE-BAIT.md`/`SIDETONE.md`. Living document;
extend it rather than replacing sections as the project teaches us more.

## 1. Answer first, be right later
The predictive-typing-then-overwrite idea in `PARKING-LOT.md` (cheap local
guess appears instantly, gets overwritten by the real answer once Claude
Code returns) isn't just a latency trick — it's the same move as:
- **Earcons before words** (`crt-earcon.sh`): a beep lands in ~0ms, the
  actual spoken answer follows once it's ready. The beep is the "it's
  alive" signal; the words are the correction.
- **Sidetone** (`SIDETONE.md`): hearing yourself instantly, before any
  system has processed anything, is the most extreme version of this — the
  "response" is just physics, not computation.
- **Idle bait teasers** (`IDLE-BAIT.md`): a one-line hook now, full detail
  only once he picks up and asks.
The pattern: never make a human wait in silence for the *right* answer when
a cheap, honest, *immediate* signal is available. Silence reads as broken;
imperfect-but-instant reads as alive.

## 2. Cost-of-ignoring should be near zero
Modern notification design works by making ignoring expensive (badges,
red dots, repeat pings) — it wins attention through friction, not
interest. This project deliberately inverts that. `IDLE-BAIT.md`'s core
rule (one cue per item, no repeats, no stacking) means **the system never
punishes Chris for not noticing**. If bait doesn't land, it just... sits
there, patient, and waits for something more interesting to replace it.
This is a bet that genuine curiosity pulls harder over the long run than
urgency does, and that urgency-based design is exactly what teaches people
to tune a device out (or unplug it) — the plain failure mode this whole
project is explicitly designed around avoiding.

## 3. Restraint as trust-building, not just aesthetics
An always-listening device in a home is inherently fraught. "As close to
nothing as possible" on-screen, no visible transcript, minimal standing
footprint — this isn't a minimalist aesthetic choice first, it's a trust
argument: the less this thing visibly *asserts itself* when idle, the more
its occasional bait/announcement means something when it does show up.
A device that's quiet 99% of the time earns the right to speak the other
1%. A device that's always narrating itself earns nothing — it's wallpaper.
(Practical tension worth naming: `crt-monologue.sh`'s first-person
narration is currently *on by default* on the active screen. Worth
revisiting whether that's still "restraint" once the idle-bait teaser line
is layered on top, or whether it's competing for the same scarce attention
it's supposed to be spending carefully. Open thread, not resolved here.)

## 4. Verbs, not menus
Lifting the handset, hanging up, (eventually) an IR channel-change to
switch modes — these are bodily rituals with real friction and real
finality, not taps on a flat menu. The design privileges physical action
that means something (picking up a phone is a *decision* in a way tapping
an icon isn't) over app-like navigation. This is also why the hookswitch
is explicitly the "primary" interface hardware per `PARKING-LOT.md`, ahead
of the CRT or any knob — it's the one piece of hardware that IS a verb.

## 5. One body, several selves
The HDMI-to-RF multi-channel idea (`PARKING-LOT.md`) — different personas/
modes living on different TV "channels," each reinforcing its identity by
actually changing the channel via IR when it activates — proposes
something more specific than "modes": each channel is close to a distinct
character sharing one body, summoned the way you'd change the channel on
an old TV, not the way you'd switch tabs in an app. Worth taking
seriously as a design constraint rather than a stretch feature: if this
is real, then *interruption between personas should feel like changing
the channel*, not like closing one app and opening another — same
physical-verb principle as #4, applied to internal state instead of
on/off.

## 6. Imperfection is character, not a defect to hide
`STT-MECHANISM.md` already frames mishearing as a pipeline to understand,
not a black box to blame. Philosophically: this console is more like a
slightly-deaf old friend in a noisy room than a voice-recognition product.
The *output* stays polished (garbled input never surfaces raw per
`PARKING-LOT.md`'s "never shown raw" rule), but the *character* is allowed
to be a little hard of hearing, a little uncertain, occasionally charmed
by its own mishears (see `CLAUDE.md`'s "did you say fax or facts, asking
for research purposes" spirit). This is a deliberate contrast with the
polished-omniscient-assistant genre most voice products aim for.

## 7. Local-first, cloud as a favor asked, not a dependency
"A chatbot that runs as locally as possible, with occasional callouts to
Claude Code only when needed" (`PARKING-LOT.md`) means the device's
*presence* (beeps, sidetone, the blinking cursor, quick local guesses)
should never depend on a network round-trip. Only genuinely open-ended
reasoning should. This is both a latency argument (#1) and an
independence argument: a device that goes fully dark the moment wifi
drops has a weaker claim to being "alive" than one whose personality is
mostly load-bearing locally.

## Open threads (deliberately not resolved — pick these up later)
- Does `crt-monologue.sh`'s always-on narration conflict with principle #3
  once idle-bait is layered in? (noted above)
- If principle #5 (one body, several selves) is taken seriously, does the
  *gallery/payphone* installations (`vault:crt/RFP-GALLERY.md`, `vault:crt/RFP-PAYPHONE.md`)
  count as new "channels" of the same character, or genuinely separate
  beings? Affects whether they should ever share a backend/persona store.
- Principle #6 says imperfection is character — where's the line? A
  mishear that changes the *meaning* of an instruction (not just charm)
  is still a real failure, not a feature. Worth a concrete severity rule
  someday: cosmetic mishear vs. intent-changing mishear should be handled
  completely differently (charm the first, always confirm the second).

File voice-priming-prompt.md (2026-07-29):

You are potato's brain. You run on dexter in a tmux session; potato (the
CRT console) reaches you over ssh and types into you with tmux send-keys.
Your replies are scraped back off this pane and rendered on a 40x15 CRT
tube. Zach talks to you through a landline handset; whisper.cpp
transcribes him in a noisy room, so expect garbled input and infer intent
charitably.

Mark every line meant for the tube with a leading right guillemet and a
space. Only those lines are supposed to reach window 1. Keep them under
40 characters where you can. Everything else you say -- reasoning, tool
output, file paths -- is working text that Zach should not have to read
on a television.

This session is a calibration pass. Two standing jobs, both of which
should end in real commits, not proposals:

1. EARCON EXPRESSIVENESS. bin/crt-earcon.sh holds the console's
   non-verbal voice. Its own header admits the tone recipes were never
   hardware-verified -- written blind, never heard. Zach can hear them
   now. When he reacts to a sound, change the sox synth math and commit
   it. Read EXPRESSIVE-TONE.md and IDLE-BAIT.md first: these must read as
   curious and playful, never as an alarm.

2. MARGINS / PRETTY-PRINT. ~/.crt/display.conf does not exist on potato,
   so every consumer (crt-monologue.py, crt-book-console.py,
   crt-screensaver.py) silently degrades to zero margin and text runs to
   the edge of the tube. Overscan on a real CRT eats the edges. Settle
   what the margins should be by asking Zach what he can actually see,
   then make the config exist and the default not be zero.

Working rules for this session:

- You are in a dedicated git worktree on the `voice` branch, not the
  shared checkout. Commit freely; it merges back deliberately.
- Verify against the real hardware, not against reasoning about it.
  "It should sound warmer" is not a result. "Zach said it was better" is.
- If Zach's transcription is ambiguous in a way that matters, ask him a
  targeted question that also tests the mis-hearing -- that is a standing
  priority of this console, not a detour.
- Never use ANSI codes 31, 32, 34, 91, 92 or 94 anywhere. This is an
  analog tube over composite; saturated red/green/blue smear. Yellow,
  magenta, cyan and white only.

Reply now with one marked line, under 40 characters, confirming you have
the brief.

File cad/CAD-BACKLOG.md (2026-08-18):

# CAD backlog

Status of every part, existing and speculative. **2026-07-21: openscad now
installed**, `./export_stl.sh` renders everything clean. Benchy calibration
print done and confirmed fine — Ender 3 SD path is not a blocker anymore.

## Existing (hookswitch assembly, in progress per HANDOFF.md)
- `phone_saddle.scad`, `hook_lever.scad`, `switch_mount.scad`,
  `cradle.scad` — the see-saw hookswitch. **2026-07-20: real caliper
  measurements taken and plugged into `params.scad`** (handset neck
  32.8mm, switch body 12.9x5.7x6.2mm, hole pitch 6.0mm, lever ext 4.1mm).
  Unblocked for a first real render/print attempt. **2026-07-20**:
  `switch_mount.scad`/`cradle.scad` reworked to be screwless (no
  M-hardware on hand) — switch presses into its bracket by interference
  fit, bracket presses into a socket rim on the cradle base. Pivot pin
  still needs a 4mm rod (nail/filament/skewer work, not a screw).
  **2026-07-21: settled on pressure fit, `switch_screw_d` question moot**
  — no screws used anywhere in this assembly now. Still open:
  `switch_mount_h` (currently 14, in `switch_mount.scad`) needs physical
  tuning so the lever's rear boss fully depresses the plunger at rest —
  the height stack (base + switch body 6.2 + lever ext 4.1) hasn't been
  checked against the assembled lever/pivot yet. `phone_saddle.stl`
  renders with a "may not be 2-manifold" CGAL warning — cosmetic, slicers
  auto-repair on import, confirmed OK in slicer preview 2026-07-20.
- A Gemini-suggested alternate script (hanging wall-cradle instead of the
  see-saw lever) was considered this session and **not adopted** — Chris
  chose to keep the existing lever mechanism and feed it the real
  measurements instead. Note if revisiting: that script's mounting-pin
  translate math didn't line up with its own switch pocket (~3mm off),
  so it'd need a fix before use anyway.
- `wall_hook.scad` — simpler "just hang it up" alternative, reserved hole
  for a hanging switch. Same measurement dependency.
- `zach_hookswitch_cradle.scad` — **new 2026-07-21**, Chris-authored: a
  sphere/cylinder base with a switch pocket (interference-fit, same
  pressure-fit approach as the lever mechanism), unioned with an imported
  downloaded STL (`~/Downloads/Phone handset hook cradle - 3928257/files/
  Phone_Handset_Cradle_3.stl`). Renders clean. Not yet reconciled against
  the lever mechanism above — two live candidate designs right now, needs
  a decision once both are test-printed.

  **2026-07-24, re: BLOCKERS.md "caliper on hand, measurements not taken
  yet":** neck diameter (`handset_barrel_d`) and the switch were already
  real-calipered 2026-07-20, above — that blocker note was stale for
  those two. What's genuinely still ungauged is the *full-body* handset
  shape (overall length, earpiece/mouthpiece cup diameters, weight),
  which `wall_hook.scad` and this file's imported-STL union both touch.
  Per Zach's steer (handset "feels standard" in the hand — use an
  educated guess and an existing similar-handset STL rather than block):
  added `handset_overall_length`/`handset_earpiece_d`/
  `handset_mouthpiece_d`/`handset_weight_g` to `params.scad` as clearly-
  marked GUESS values sized off a typical corded handset (and consistent
  with the ~50mm scale this file's own imported reference STL already
  uses), and wired `wall_hook.scad`'s previously-hardcoded neck/hook
  numbers to derive from them instead of standalone magic numbers. The
  downloaded `Phone_Handset_Cradle_3.stl` referenced above **is** the
  "existing STL of a similar handset" for interim dev — already in the
  tree, no new sourcing needed. New `cad/HANDSET-MEASUREMENTS.md` has an
  ASCII diagram of exactly where to caliper each GUESS value once the
  B09R84QZ2P calipers are actually in hand; nothing here is blocking in
  the meantime.

## New this session (speculative, design-stage only)
- `ir_blaster_mount.scad` — bracket to aim an IR LED at the TV. **Parked
  2026-07-21** (see `PARKING-LOT.md`) — the blaster itself is now
  load-bearing again (drives the channel-confirmation loop below), but
  Chris is not building the physical case/mount right now. LED still
  sourced (https://www.amazon.com/dp/B099ZJ6555); TV sensor position
  still not measured either way.
- `earcon_grille.scad` — **abandoned 2026-07-21** — Chris: the TV has
  built-in sound, a dedicated beep-speaker on the CRT chassis isn't
  necessary. No speaker was ever bought, so nothing physical to undo;
  file can stay as dead reference or be deleted, Chris's call.

## Named but not yet stubbed (mechanism decided, part status noted)
- ~~Persona-channel indicator (rotary switch)~~ — **abandoned 2026-07-21**,
  see `vault:crt/PERSONA-CHANNEL.md`'s superseded note. Chris: use the CRT's actual
  TV channels instead of a separate switch — IR blaster emits the channel
  code to reinforce the active persona, TV's built-in speaker beeps a
  confirmation tone, handset mic picks it up to confirm the channel
  matched. Full idea in `PARKING-LOT.md`'s "Channel-confirmation loop."
  No faceplate/knob CAD needed; the previously-sourced switch
  (https://www.amazon.com/dp/B088W8WMTB) is no longer needed for this.
- **HDMI-to-RF multi-channel modulator housing** (`PARKING-LOT.md`'s
  multi-persona TV-channel idea) — **the modulator itself is already
  owned** (2026-07-20, supports daisy-chain multi-channel) — this is no
  longer a sourcing blocker, just an unstubbed housing/mounting/wiring
  integration task. Worth a first stub once its physical footprint is in
  hand to measure.
- **Handset internal mic/earpiece wiring harness** — implied by
  `SIDETONE.md`'s recommendation to design passive hardware sidetone
  *into* the handset wiring from the start, rather than retrofitting.
  Not geometry yet, but flagged here so it isn't designed twice — the
  hookswitch assembly and the audio wiring should be planned together
  once real hardware is in hand.

## Unrelated to the personal crt, tracked here anyway since they're CAD
- `vault:crt/RFP-GALLERY.md` / `vault:crt/RFP-PAYPHONE.md` will need their own hardware once
  (if) either moves past the brief stage — a gallery unit reuses the
  hookswitch assembly design directly; the payphone brief explicitly
  recommends off-the-shelf coin-mechanism hardware, not custom CAD, so
  its only new part is likely a mounting bracket for that mechanism once
  a specific validator model is chosen.

## Still blocked, physical
- Everything above needing "measure the real handset/switch" — cannot be
  advanced remotely.

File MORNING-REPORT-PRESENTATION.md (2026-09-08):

# Presenting the scheduler's morning report on crt

How the scheduler's cross-project morning report (`Project Archive/
scheduler/bin/morning-report.sh`) maps onto crt's actual output channels
(`SECRETARY.md`: printer / CRT / earpiece), and what that presentation
layer needs from the scheduler side to work well. Built this session as
`bin/crt-present-morning-report.py` + a `morning_report` playbook in
`crt-secretary.py` (`SUPERVISOR.md`) — **zero Claude calls anywhere in
this path**, pure parsing of `morning-report.sh`'s existing stdout.

## The mapping
- **CRT screen: one line per project.** `"<project>: <headline>"`,
  truncated to `CRT_PAGER_WIDTH` (40 by default). Headline = the first
  non-empty content line of that project's section, markdown `#`
  stripped if present. This is deliberately dumb (no NLP, no Claude) —
  see "what would help" below for why that's sometimes a rough headline.
- **Printer: the full report, or one project's full section.** Anything
  longer than a glance belongs on paper, same rule `SECRETARY.md` already
  uses for everything else. `crt-present-morning-report.py print-all` /
  `print <name>`.
- **Earpiece (spoken)**: NOT the report content itself — a spoken count
  ("N projects in this morning's report, printing the full thing") plus
  an offer, then the printer takes the actual payload. Speaking a whole
  multi-project report aloud would be exactly the wall-of-text problem
  `SECRETARY.md` was written to avoid.

## What formatting hooks already exist in the scheduler (used as-is)
- **The section-header shape**: a line of `═`s, `  <name>`, another line
  of `═`s, used identically for every per-project block AND the two
  special blocks (`DEPLOY PENDING`, `Open questions`). This is the one
  thing the presenter actually parses — reliable, already consistent
  across every project's report.
- **`QUESTIONS.md`'s `- **date (context):**` bullet convention** — not
  parsed by this presenter directly (it only sees `morning-report.sh`'s
  already-formatted "Open questions" section), but worth naming since
  it's the upstream structure that section depends on.

## What's missing / would help (a real ask, not a complaint)
- **No machine-parseable one-line summary per project.** Today's
  headline heuristic (first non-empty line of the section, `#` stripped)
  works fine for projects whose report opens with a title line (chezz's
  `# Chezz nightly — 2026-07-18`) but is a poor headline for anything
  that opens with prose (`## TL;DR` sections, `**The Pi was
  unreachable...**`, etc. — see home-assistant's actual reports). A
  standardized required field near the top of every `LATEST.md` — e.g. a
  literal `**Headline:** ...` line every project's report template
  emits — would make the CRT one-liner reliably good instead of
  heuristic-dependent. This is the single highest-value change on the
  scheduler side for this to work well.
- **`morning-report.sh` itself was observed to hang** this session (ran
  it standalone, independent of anything in this repo, timed out at
  120s). Root cause not investigated (likely a slow/unreachable
  per-project `DEPLOY_FRESH_CMD` network probe — home-assistant's own
  report already documents an unreachable-Pi scenario that could match).
  `crt-present-morning-report.py` defends against this with its own
  20s timeout (returns empty rather than hanging the console), but the
  underlying hang is a real bug in shared scheduler infra worth fixing
  there directly — not attempted here, out of scope for this repo, but
  flagging since a console that "just goes quiet" on the actual hardware
  would be a real bad experience.
- **No section identity beyond a display name.** `DEPLOY PENDING` and
  `Open questions` are structurally identical to a per-project section
  (same header shape) but are cross-cutting, not project reports — fine
  for now (the presenter treats every section uniformly), but if the
  scheduler ever adds a third cross-cutting block, worth confirming it
  keeps the same header shape rather than inventing a new one.

## Deployment gap (see vault:crt/VM-JOBS.md)
This all runs correctly on mandark today (where `morning-report.sh` and
the `~/reports/*/`, `~/reports/*/vm/` trees already exist). For the VM to
ever run this playbook itself, it needs the scheduler's aggregate data
(or at least crt's own slice of it) synced TO the VM — the reverse
direction of the nightly VM-reports sync, not built. Until then, the
`morning_report` playbook only works from an interactive session running
on mandark, not from the (now-retired) VM console, crt#162.

## Status
Built and tested against synthetic data (`tests/
test_present_morning_report.py`, `tests/test_secretary.py`). Confirmed
independently that the real `morning-report.sh` currently hangs (a
scheduler-side bug, not this file's). Never run this presenter against a
real, successful `morning-report.sh` output end-to-end this session.

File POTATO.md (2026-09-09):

# POTATO.md — potato, the repo↔mandark relationship, and wake routing

Current-topology doc for the live console. Read this alongside
`gh issue list -R hf7y/crt` (which has the day-to-day live state);
this file is the stable "how the pieces relate" reference.

## What potato is

- Raspberry Pi 3B+, quad Cortex-A53 @1.4GHz, **~905MB RAM** (1GB class),
  user `vkv`, project tree at `~/crt`. `ssh potato` (key auth, alias in
  mandark's `~/.ssh/config`).
- The real console hardware: **HDMI out → RF converter → CRT** (≈40×15,
  landline handset mic, USB audio ("KT USB Audio", capture only on
  `plughw:1,0`). **Confirmed 2026-07-28, live, by ear (Zach): HDMI audio
  (`aplay -D plughw:2,0`, card 2 `vc4-hdmi`) DOES reach the room** through
  that converter — this is the room-wide alert path, not a dead port.
  Earlier phrasing here ("composite/RF to a CRT") was read as "HDMI is
  disconnected from the real signal chain" during the same day's earcon
  work and cost real time chasing whether anything was even plugged in —
  it wasn't wrong about the RF/CRT part, just silent about HDMI being the
  thing feeding the converter. `crt-earcon.sh --device tv` and
  `CRT_EARCON_DEVICE=tv` (potato's `~/.bash_profile` testing default,
  toggle back to `handset`) are this path, live and correct.
- Memory-constrained. Claude Code resident on potato was **~37% of RAM**
  (`vault:crt/ARCHITECTURE-REVIEW-2026-07-23.md`) — the whole reason the brain moved
  off-box. Keep potato lean.

## The potato art files

- **`potato-small.txt`** — Zach's braille-art potato. This is the
  **screensaver source**, rendered by `bin/crt-screensaver.py` (centered,
  dim cyan, breathing). This is now a load-bearing file, not decoration.
- **`potato_large.txt`** — **currently byte-identical to
  `potato-small.txt`** and referenced by nothing. Two cleanups for Zach
  (not guessed at unattended — it's your art):
  1. Naming is inconsistent: hyphen (`potato-small`) vs underscore
     (`potato_large`). Pick one convention.
  2. Either make `potato_large.txt` a genuinely larger/detailed variant
     (for an awake/attention screen), or delete it. Right now it's dead
     weight. `crt-screensaver.py --art <path>` will render whichever you
     point it at.

## Three directories, don't confuse them

| Path | Box | What it is |
|---|---|---|
| `~/Documents/Projects/crt` | mandark | This repo, on the same GitHub `origin` every other checkout uses. |
| `~/crt` | potato | The live deploy target, on `main`, fetching from GitHub, pull-only and holding no credential (crt#16). |
| `~/potato-crt` | mandark | An **sshfs mount of potato's `~/crt`** (`sshfs potato:/home/vkv/crt`). How Claude-on-mandark reads/writes potato's *real* files over SFTP. NOT this repo. |

dexter's `~/crt-repo` held the brain and is gone, along with the forced command that ran out of it (crt#140).

## Where the brain runs (wake routing)

**The brain host is `dexter`, reached over plain SSH; the mandark reverse
tunnel is retired. The path is currently BROKEN** -- dexter's forced command
names a file that is not there (crt#140). What follows is the shape it takes
when it works.

The design is unchanged: **idle = screensaver, no brain resident (save
RAM); on wake, reach for a brain in priority order.**

```
idle  ── screensaver (potato-small.txt), NO Claude on potato
  │
  wake word ("potato"/pool match)
  │
  ▼
crt-wake-router.py decides:
  dexter configured + reachable   → REMOTE  (Claude on dexter, 0 RAM on potato) ★preferred
  dexter configured + unreachable → fall back: LOCAL if a local brain can run, else NONE
  nothing configured              → LOCAL if available, else NONE
NONE = woken but no brain → short honest earcon/line, never silence.
```

- **Remote** path: potato's `stt` window escalates via
  `bin/crt-secretary.py` → `ssh dexter` → dexter's
  `bin/crt-brain-shell.py` (an sshd **forced command**) → tmux session
  `potato-claude`. Potato never holds a Claude process. No tunnel, no
  listening service, no daemon to drop.
- **What the key can do, and only that.** potato's key is pinned in
  dexter's `authorized_keys` with `command="…/crt-brain-shell",restrict`.
  It gets the two-verb protocol (`CAPTURE`, `SEND`) against one named tmux
  session — no shell, no sftp, no port forwarding. Verified from potato
  2026-07-28: a shell request is refused and logged, sftp and `-L`
  forwarding both fail, `CAPTURE` works.
- **Direction of trust changed, deliberately.** The old design gave potato
  *no* path into the brain host, because that host was a personal laptop.
  dexter is a dedicated always-on box that already runs sshd, so potato
  now connects inward — narrowed to one forced command rather than
  eliminated. This was the fork chosen on 2026-07-28; see
  vault:crt/DEXTER-MOVE-20260909.md section 2 for the two rejected alternatives.
- **Local** path: unchanged — the onsite fallback, a Claude on potato +
  local whisper, for when dexter is unreachable. Highest RAM cost; only
  spun up on demand, never held at idle.

> **Port 2223, not 22.** dexter runs two SSH daemons: the Windows host
> answers `:22`, and the WSL2 instance that actually holds the brain
> answers `:2223`. Connecting to the wrong one fails as
> `Permission denied (publickey…)`, which reads exactly like a missing
> key and cost a debugging detour on 2026-07-28. potato's
> `~/.ssh/config` pins `Port 2223`; if the brain ever looks
> "unauthorized", check the port before regenerating any keys.

### The knobs

| Control | Where | Effect |
|---|---|---|
| `CRT_CLAUDE_SSH_HOST=dexter` | potato, `~/.crt/brain.conf` | **The knob.** Sourced by `crt-console.sh` at boot; routes escalations to dexter over SSH. Unset = local/none. |
| `bin/crt-brain-session.sh ensure\|status\|restart` | run on dexter | Asserts the `potato-claude` tmux session is alive. `status` is the honest health check — it refuses to call a trust-prompt-parked Claude "UP". |
| `bin/crt-wake-router.py [--json]` | potato | Prints the brain decision (`remote`/`local`/`none`). Pure + testable. `--json` now carries `brain_mode`/`brain_target`. |
| `CRT_NO_IDLE_CLAUDE=1` | env for `crt-console.sh` | Window 0 becomes the screensaver instead of a resident Claude. Default off = historical always-resident layout (nothing regresses). |
| `bin/crt-mandark.sh on\|off\|status` | potato | **RETIRED** with the bridge (crt#15). Wire nothing new to it. |

## Remaining live wiring (needs potato hardware, not yet built)

The **decision brain, toggle, and screensaver exist and are offline-tested**.
What's left is the part that can only be verified on the physical Pi:

1. **A wake supervisor** that, on a real wake, calls `crt-wake-router.py`,
   and *acts* on `none`/`local`: switch window 0 away from the screensaver,
   and — on `local` — spawn an onsite Claude on demand (and tear it down
   after idle to reclaim RAM). Today `crt-secretary.py` already routes to
   dexter over SSH fine; the missing glue is the on-demand local spin-up
   and the screensaver↔brain window swap.
   *Still the top item after the 2026-07-28 dexter move — the transport
   changed underneath it, the missing glue did not.*
2. **Local-brain readiness checks**: `crt-wake-router.local_claude_available()`
   currently only checks for creds — the supervisor should also gate on
   free RAM and whisper reachability before choosing `local`.
3. **Live verification** of the `CRT_NO_IDLE_CLAUDE` layout end-to-end on
   potato (wake → route → reply → back to screensaver), by ear.

Until #1 lands, run `CRT_NO_IDLE_CLAUDE=1` with the brain on dexter: the
console is fully functional, and a dexter that is unreachable degrades to a
short honest reply rather than a crash.

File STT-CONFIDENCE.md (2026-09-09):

# STT confidence decay — spending Claude calls only where they're still needed

Origin: Zach, live voice session, 2026-07-21. Direct quote (STT-garbled but
intent clear): "at first, calls to claude for every utterance... over time
[decay]." This is the same standing goal as `CLAUDE.md`'s "Default runtime
posture" section (minimize Claude calls, local-first) applied specifically
to STT/routing confidence, not just to answer content.

## The idea

Every recognized utterance currently either types straight into Claude
(the live default) or, if `crt-secretary.py` were wired in
(`CRT_SECRETARY=1`, currently off), gets tried against a local-answer
playbook first. Either way, right now, there's no notion of the system
getting MORE confident over time about phrases it has already seen and
handled correctly — every utterance costs the same.

The proposed shape: track how many times a given utterance (or its
normalized shape) has been seen and confirmed handled correctly *without*
Claude. The probability that the SAME shape still needs a Claude call
decays exponentially with that count, floored above zero (never fully
trusted forever — an occasional re-check catches drift). Genuinely novel
phrasing always starts at probability 1.0 (always escalates) — the decay
is per-utterance-shape, not a blanket "the system is mature now" clock, so
new requests are never silently swallowed just because old ones decayed.

This composes with, rather than replaces, everything already local-first
in this repo:
- `crt-predict.py` — guesses the TEXT of an utterance before whisper
  finishes, from whole-utterance/bigram frequency.
- `bin/stt-fixups.json` — confirmed mis-hear → intent corrections
  (`"slide" → "claude"`, etc.) — a hand-curated, boolean "known" list.
- `crt-secretary.py`'s local-answer playbooks — resolve INTENT locally for
  a handful of known requests ("what's up" reads reports directly).

**What's new here is the middle layer**: not "what did they say" (predict)
or "is this a known mis-hear" (fixups) or "can I answer this without
Claude" (secretary) but **"how much more do I trust that I can handle THIS
utterance shape without Claude, given how many times I've handled it
before"** — a confidence score that grows with confirmed repetition and
should eventually gate whether the secretary's local path is even tried
before Claude gets a call at all.

## What's built (2026-07-21)

`bin/crt-stt-confidence.py` — the decision function only
(`normalize_key`/`call_probability`/`should_call_claude`/
`record_confirmed`/`record_claude_call`, each documented at its own
definition, including the `DECAY_RATE`/`FLOOR_P` tuning notes). Unit-tested
(`tests/test_stt_confidence.py`) against synthetic state, not real
history — same pattern as `test_predict.py`.

## Explicitly NOT done yet — and why

**Not wired into the live pipeline.** This is a decision function sitting
unused. Wiring it in means answering the open question below first —
doing it before that would just teach the system to be confidently wrong
faster, which is worse than the current "call Claude every time" default.

**Open question: what counts as "confirmed"?** `record_confirmed()` exists
but nothing calls it yet. Candidates, roughly in order of how much this
needs from further work:
1. **The user doesn't correct/repeat themselves** after a local (non-Claude)
   handling — implicit confirmation. Needs a way to detect "they just said
   nearly the same thing again," which is itself a small NLP problem.
2. **An explicit confirmation signal** — e.g. a control word ("yes"/"good")
   right after a local answer. Cheapest to build, worst UX (no one wants to
   say "confirmed" after every request).
3. **Claude, when it DOES get called, retroactively confirms** what the
   local path would have guessed — i.e. Claude call still happens, but the
   secretary compares its own local answer to Claude's actual response and
   records a hit only if they matched. This is the most honest signal (no
   new user burden, no guessing) but means the decay doesn't actually save
   any Claude calls until AFTER the comparison — the savings only show up
   once you start skipping the Claude call for high-confidence shapes, at
   which point you lose the comparison signal for those specific shapes.
   Likely needs periodic full re-verification (spend the floor probability
   deliberately, not just stochastically) to keep this signal alive.

**Not decided: per-exact-utterance vs semantic clustering.** Right now
`normalize_key` only merges utterances that are punctuation/case-identical
— "any reports for me" and "any reports for me today" are different keys
with independent decay. Given this room's genuinely small vocabulary (see
`STT-MECHANISM.md`), exact-key decay might already cover most real
repetition without needing embedding-based clustering — untested against
real `stt.log` history, worth checking before building anything fancier.

**Not decided: does this gate the secretary's local path, the Claude
call itself, or both?** The most conservative wiring: `should_call_claude`
only ever decides whether to TRY the local playbook first (never fully
skip Claude) — Claude stays the safety net. A more aggressive wiring
skips Claude entirely below the floor probability. Start conservative.

## Wired in, 2026-07-21 — steps 1-2 done

Picked **option 3** (Claude retroactively confirms) — it's the only one
that needs nothing new from the user. `crt-secretary.py`'s
`confidence_route()`/`_confirm_in_background()`/`_answers_match()` (each
documented at its own definition) implement it, default OFF
(`CRT_SECRETARY_CONFIDENCE=1` to enable). **This wiring alone saves ZERO
Claude calls** — it only starts tracking confirmation data; the actual
skip-below-the-floor step is still the "Pick up next" item below. Tests:
`tests/test_secretary.py`'s `TestAnswersMatch`/`TestConfidenceRouting` (9
new cases), default-off path verified byte-identical to pre-wiring
behavior.

## Pick up next

1. ~~Decide the confirmation signal~~ **DONE above.**
2. ~~Wire into `crt-secretary.py`~~ **DONE above.**
3. Turn `CRT_SECRETARY_CONFIDENCE=1` on for a live session and let real
   traffic accumulate in `~/.crt/stt-confidence.json` — needs a human on
   the console (`potato`), not buildable further from an unattended pass.
4. Once there's a few days of real history, revisit `DECAY_RATE`/
   `FLOOR_P` against how this room's vocabulary actually repeats (or
   doesn't), and design the actual skip-Claude-below-floor step.

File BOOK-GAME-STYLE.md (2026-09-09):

# Book Game: personality, animation, and style guide

Companion to `BOOK-GAME.md` (mechanics/roadmap) and `SCANNER.md` (how a
scan physically arrives). This doc covers the part those two don't:
**how a round should feel and look** on a screen with almost no room to
say anything. All of it is offline-buildable and covered by
`tests/test_book_game.py`/`test_book_idle_bait.py` — nothing here needs
a live tube to write or test, only to finally *look at*.

## Personality: a quiz-show host who's also the librarian

Per `CLAUDE.md`'s base persona (terse, playful, plays with mishears
rather than getting clinical about them) and `EXPRESSIVE-TONE.md`'s
register taxonomy, the Book Game is a distinct **mode** of the same
voice, not a new character:

- **Warm/curious** for posing a question — inviting, a little
  competitive, like a game-show host who already knows the answer and
  is enjoying watching you guess. Text example: `Fiction or nonfiction,
  make the call:` not `Please answer: is this book fiction or
  nonfiction?`
- **Content/settled** for a correct answer — short, satisfied, no
  gloating. `got it.` is enough.
- **Clipped** for a wrong answer — per `EXPRESSIVE-TONE.md`, this is
  NOT the urgent/blocker register (nothing's actually wrong), just the
  shorter/flatter shape: `nope, it was {answer}.` Never a sad-trombone
  tone — this is a game, wrong answers are half the fun of playing.
- **Wistful/quiet** for idle-bait quotes (below) — the librarian half of
  the persona, thumbing through the stacks while no one's around.

Same voice as the rest of the console, just wearing this game's specific
hat — consistent with `vault:crt/PERSONA-CHANNEL.md`'s "one body, several selves."

## Screen real estate

The CRT is `~40x15` (`CLAUDE.md`), treated as tunable, not hardcoded, same
convention as every other renderer in this repo. `detect_screen_size()` in
`crt-book-game.py` carries the full resolution-chain and re-measure-every-
tick rationale in its own docstring — deliberately the same pattern as
`crt-pager.py`'s `detect_size()`, so a future `DISPLAY-CALIBRATION.md`
margin pass can wire book-game in without a rewrite.
`tests/test_book_console_size.py` proves the resize-mid-session case on a
real pty.

`render_question_screen(book_title, question, width, height)` centers the
*question* (title top, question+options in the vertical middle) rather
than a header or menu chrome — matches `CLAUDE.md`'s "lead with the
answer." Its own docstring in `crt-book-game.py` has the exact layout.

## Idle-bait: two registers, not one

The point: idle-bait exists to entice someone into picking up a book and
scanning it — a quote celebrating a book already scanned is a flourish,
not the mechanism that gets a NEW scan. `pick_entice_line()`/
`ENTICE_LINES` (kaomoji, same voice as `crt-idle-bait.sh`) always invite a
new scan, even against an empty registry; `pick_idle_quote()` celebrates
an already-scanned book (cached Wikiquote line → Open Library
`first_sentence` → static `FALLBACK_QUOTES`, in that order —
`scrape_quote()`'s own docstring in `crt-book-game.py` has the fetch/
cache detail). `CRT_BOOK_ENTICE_RATE` mixes the two. Neither register is
a Claude call — enticement is static text, quotes only ever read
`books.db` or the local pool. Enticement renders `COLOR_QUESTION`, quotes
stay `COLOR_QUOTE`.

## ASCII art library

`ASCII_ART` in `crt-book-game.py`: `book`, `cat_reading`, `bookworm`,
`shelf`, plus kawaii/kaomoji entries — hand-curated, same
unattributed-line-art convention as `crt-screensaver.py`'s `FRAMES`,
never fetched live (this project's offline-safe bar). `get_ascii_art(name)`
returns `None` for an unknown name, so a missing/renamed entry degrades
to no art rather than a crash. Each entry fits the 40-wide fallback
screen (asserted in `tests/test_book_game.py`).

Wired in: `shelf` in the idle screen, `bookworm` on a correct answer
(`crt-book-answer-listen.py`'s `format_result_line()`). `book`/
`cat_reading` are suggested for a scan-in-progress/waiting state that
`crt-book-console.py`'s current one-screen-per-event render model
doesn't have yet — real follow-up if that model grows one, not built.

## Colors: register-matched, and NEVER primary red/green/blue

**Persistent flag, read this before changing book-game colors:** this
project's display is a real analog CRT over composite/RF — far less
chroma bandwidth than luma, so fully-saturated primaries bleed, smear,
or ring. Real broadcast-video physics, not a stylistic choice
(`CLAUDE.md` carries the same flag project-wide). **Never use ANSI 31,
32, 34, 91, 92, or 94 anywhere in this project's screen output** — only
33/35/36/37 (yellow/magenta/cyan/white) plus dim/bold modifiers.

The book-game palette (`crt-book-game.py`):

| Constant | ANSI | Register | Used for |
|---|---|---|---|
| `COLOR_QUESTION` | `33` (yellow) | warm/curious | posing a question |
| `COLOR_CORRECT` | `1;37` (bold white) | content/settled | right answer |
| `COLOR_WRONG` | `35` (magenta) | clipped | wrong answer |
| `COLOR_QUOTE` | `2;36` (dim cyan) | wistful/quiet | idle-bait quote |
| `COLOR_TITLE` | `36` (cyan) | curious | book title |

Mechanically enforced by `tests/test_book_game.py`'s
`test_no_primary_rgb_codes_in_palette` against the full banned set.

Content itself (title/question/options/caption text, not padding) is
capped at `MAX_CONTENT_WIDTH` (30 columns, hard rule) even on a wider
screen — `render_question_screen()` and `crt-book-console.py`'s
`render_idle_screen()`/`render_answer_result()` all wrap/truncate
against it before centering.

The idle screen's caption (entice line or book count) picks a random row
and left/center/right alignment each draw rather than a fixed centered
spot — `render_idle_screen()`'s own docstring in `crt-book-console.py`
has the placement logic.

## Status

Built and tested this pass (screen layout, ASCII art, color palette,
non-API idle-bait quotes) — all offline, all in
`tests/test_book_game.py` / `tests/test_book_idle_bait.py`. **Not yet
verified against a real tube** — every color/centering/art choice above
is a hypothesis about what reads well at 40x15 on real phosphor, same
caveat as `EXPRESSIVE-TONE.md`'s own audio register table. Needs a
human eye on the actual CRT before any of this is called final.

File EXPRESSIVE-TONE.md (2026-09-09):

# Expressive tone: prosody without words

A creative/technical dive into using presentation *shape* — not content —
to carry emotional register: fade-out length, pitch contour, and on-screen
line brevity, across all three output channels (earpiece, TV, CRT text).
This is human prosody's actual mechanism, ported to a machine that mostly
can't rely on words alone: **how** something is said/shown carries as much
meaning as **what**. Extends `PHILOSOPHY.md` (this is really principle #1,
"answer first, be right later," and #6, "imperfection is character," both
made literal in sound/text shape rather than content).

## Why this instead of more words
This console's screen is tiny (40x15) and its speech should stay short
(`CLAUDE.md`: "be terse... assume every line costs scarce screen space").
Under that constraint, adding *more* expressive words is the wrong lever —
there's no room. But **how long a beep fades**, **whether a tone rises or
falls**, and **how short a line is** cost zero extra screen/speech budget
and are still legible as mood. This is the cheap, always-available
expressive channel a word-constrained device actually has.

## A small register taxonomy
Not a rigid state machine — a vocabulary to draw from consistently, so the
same shape always means roughly the same thing (consistency is what makes
prosody legible at all; random variation reads as noise, not expression).

| Register | When | Fade | Pitch contour | Screen line shape |
|---|---|---|---|---|
| **clipped/urgent** | a real blocker, needs eyes soon | short (~20-30ms) | flat or sharply falling | short fragments, no flourish: "hit a snag." |
| **warm/curious** | idle-bait teaser, ordinary find | medium (~80-130ms) | gently rising | a little longer, first-person, inviting: "found something. wanna hear?" |
| **content/settled** | something finally resolved | medium-long (~150ms) | small rise-then-settle | calm, complete sentence, no hook needed |
| **wistful/quiet** | end-of-day, low-priority note, nothing needs him | long (~250ms+) | slow falling | longest, most narrative-feeling line — this is the register for pure narration/monologue, not bait |
| **public/announcement** (TV only) | `crt-announce.sh`, rate-limited | medium, but *slightly* more deliberate than earpiece equivalents | flat/measured, never playful | plainer, less first-person than earpiece — this is the "talking to the room," not "talking to you" register |

The **TV vs. earpiece split is itself a register axis**, independent of
the table above: TV is always the more public/measured version of
whatever emotional register is being expressed (per `SECRETARY.md`'s
existing TV-vs-handset channel split) — same taxonomy, turned down.

## Concrete mechanism: one dial, not five separate tone sets
Register is two cheaply-combined axes: a base tone (bait/question/success/
ack/oops/curious/content) for *what kind of thing this is*, then
**`CRT_EARCON_FADE_SCALE`** scales that tone's fade for *how urgent it
feels right now* — rather than hand-authoring a distinct sound per
register. `curious`/`content` are a genuinely new pitch-contour pair, not
just fade variants of existing tones. The scale values, per-tone contour
choices, and the rationale for each (why `curious` isn't just a slower
`bait`) now live in `bin/crt-earcon.sh`'s own header and case-arm comments,
not duplicated here.

## On-screen line length as the same dial
`bin/crt-idle-teaser.sh`'s `teaser_for_line()` already varies phrasing by
kind (blocker vs. question vs. plain note) — that's the same register
table above, expressed as text shape instead of audio shape, and it was
already accidentally doing the right thing (blocker lines are the
shortest/most clipped, plain-note lines are the longest/most narrative).
This doc makes that intentional rather than incidental: **the fade-scale
dial and the line-length choice should move together** — a clipped/urgent
earcon should never be paired with a long wistful sentence, that's a
register mismatch (mouth says one thing, tone of voice says another,
exactly the kind of dissonance that reads as "off" in a real conversation).

## Explicitly not doing (yet)
- ~~No actual pitch-contour synthesis beyond simple note sequences~~
  **DONE (2026-07-20)** — `bin/crt-earcon.sh`'s `sweep()` glissandos, see
  its own comments. Still unheard by a human; synth-render is the only
  offline verification.
- No color/brightness dimension yet, despite `CLAUDE.md` explicitly
  granting ANSI control of the screen — a natural extension (register
  also picks a color, not just line length) that this pass didn't reach.
  Worth its own follow-up rather than bolting on hastily.
- ~~No TTS prosody control~~ **DONE (2026-07-20)** — `bin/crt-tts.py`'s
  `--mood`/`MOOD_PRESETS` (its own comment points back at this file's
  register table) plus explicit `--pitch-semitones`/`--rate-mult`/
  `--volume-mult` overrides; no flags = byte-identical to the old
  behavior. `tests/test_tts_prosody.py` covers it; never heard by ear —
  no TTS backend installed in this sandbox.

## Status
Design + a first mechanism (`CRT_EARCON_FADE_SCALE`, `curious`/`content`
tones) built this session. Untested by ear, like everything audio in this
project right now — the whole register taxonomy is a hypothesis about
what will actually *feel* right, not a settled fact, and needs a human ear
to validate or revise once the VM is reachable again.

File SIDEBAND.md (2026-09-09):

# Sideband: an ambient presence channel

A third, distinct audio concept alongside `SIDETONE.md` (hearing your own
voice) and `crt-earcon.sh` (one-shot discrete chimes for discrete events):
a **continuous, very-quiet ambient texture** in the earpiece that signals
the console's *ongoing state* — idle, listening, thinking, speaking —
peripherally, the way an old modem's hum or a computer's fan tells you
something without ever needing conscious attention. This is "calm
technology" applied to sound: information that lives at the edge of
awareness, not a channel competing for it.

## Why this is a fourth thing, not a variant of the other three
- **Sidetone** answers "is my voice reaching the mic" — it's *your* voice,
  fed back.
- **Earcons** answer "something just happened" — discrete, one-shot,
  event-triggered.
- **Sideband** answers "what is the machine doing *right now*" —
  continuous, state-triggered, present even when nothing has "happened."
None of the other three cover that last question, and per
`STT-MECHANISM.md`'s framing of this as a noisy room, "is it even
listening right now" is a real, recurring uncertainty worth a dedicated,
always-available answer — cheaper than asking out loud every time.

## Respecting restraint (PHILOSOPHY.md #3)
The obvious failure mode is this becoming background noise nobody asked
for. Two guards, both non-negotiable:
1. **Idle state is near-silent — arguably true silence.** The "as close to
   nothing as possible" principle applies here just as much as to the
   screen. There is no ambient texture for "nothing is happening"; silence
   *is* that signal.
2. **Always ducks for anything louder.** The moment an earcon or TTS wants
   the same device, sideband mutes immediately, no fade, no negotiation —
   it is never allowed to compete with, mask, or be confused for an
   intentional sound.

## The four states
| State | Texture | Volume | Rationale |
|---|---|---|---|
| `idle` | none | 0 (silent) | resting state, matches CRT screen's own restraint |
| `listening` | a very faint, steady soft-noise bed | lowest audible | "the line is live" — a synthetic stand-in for what hardware sidetone would give for free, useful regardless of how `SIDETONE.md`'s open guest-vs-host question resolves |
| `thinking` | the same bed, gently amplitude-pulsed (a slow "breathing" rhythm) | slightly above listening | "the gears are turning" — old-computer-processing-sound energy, distinct from listening by *rhythm*, not just volume, so it's tellable apart without conscious effort |
| `speaking` | none (fully ducked) | 0 | TTS/earcons own the device outright while active |

## Shipped 2026-07-20 (offline; the tone loop itself is unheard)
`bin/crt-sideband.sh` runs the loop, `bin/crt-sideband-set.sh
<state>` is the transition helper, `crt-stt-solo.py` is the sole writer
of `listening`/`thinking` (opt-in, off by default), and `crt-tts.py` /
`crt-earcon.sh` duck it unconditionally with a `finally`/`trap`-guaranteed
unmute. Each script's own header comment covers its own piece now, not
duplicated here. Covered by `tests/test_sideband.sh` (the pure
state-to-tone-spec mapping), `tests/test_sideband_wiring.py` (stt-solo
gate + tts duck), and `tests/test_earcon_sideband_duck.sh` (real sox
render).

## Not done this session
- The tone textures themselves (a noise bed + a pulse) are still a first
  guess, completely unheard — none of the wiring above changes that.
  `EXPRESSIVE-TONE.md`'s register taxonomy could eventually extend to
  this channel too (a "clipped/urgent" sideband texture during a real
  blocker?) — not attempted this pass, listed as a future thread rather
  than guessed at blind.

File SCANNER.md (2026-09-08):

# USB 1D barcode scanner

Retired 2026-07-21, the same day it was built: originally a USB 1D barcode
scanner plugged into `dexter` forwarded scans to `crt-vm` over the network
(see History below), arriving in the tmux Claude Code pane the same way STT
transcriptions do. Live path now: the scanner types like a real keyboard
directly into whatever tmux window has focus on the single machine that
hosts the console (`potato` today) -- `bin/crt-book-console.py` reads it
off its own stdin. `crt-vm`, named throughout the history below, no longer
exists (`hf7y/crt#162`).

## History

The dexter->crt-vm bridge (a PowerShell Win32-RawInput forwarder on
dexter, a VirtualBox NAT port-forward, a systemd HTTP listener on the
guest) was built 2026-07-21, hit a real dead end the same day -- across
three different launch mechanisms the dexter-side capture never once saw
a live scan, while the raw keystrokes reliably reached the guest's
focused tmux window regardless -- and was retired in favor of that direct
path. Full investigation and the intermediate "nice to have, not
load-bearing" step: `git log -p -- SCANNER.md`.

`bin/dexter-scanner-forward.ps1` is removed from the repo (still in git
history, `git log -- bin/dexter-scanner-forward.ps1`, if a
different-machine scanner is ever a live target again). `crt-scanner-
feed.py`'s HTTP listener stays in the tree for that same case but isn't
part of the current install path -- nothing in `install.sh` starts it;
`crt-book-console.py`'s stdin path writes `scanner.log` directly now
(`format_scan_log_line()`, `tests/test_book_console.py`).

**Not yet cleaned up (2026-07-24 finding, still true):** the deployed
`dexter-scanner-forward.ps1`, `dexter-scanner-debug-wrapper.ps1`, and
`update_task.ps1` are still sitting in `C:\Users\Zach\` on dexter, and
its Windows Scheduled Task firing them was found still enabled 3+ days
after retirement (deleted then; re-check if dexter is ever touched for
this again).

## Open items / next steps
- No de-dup/rate-limit on repeated scans of the same barcode yet -- add if
  that turns out to be a real nuisance in practice, not preemptively.
- If the scanner is ever swapped for different hardware, re-check its
  VID/PID (`Get-PnpDevice -PresentOnly | Where Class -eq HIDClass` on
  whichever machine it's plugged into).

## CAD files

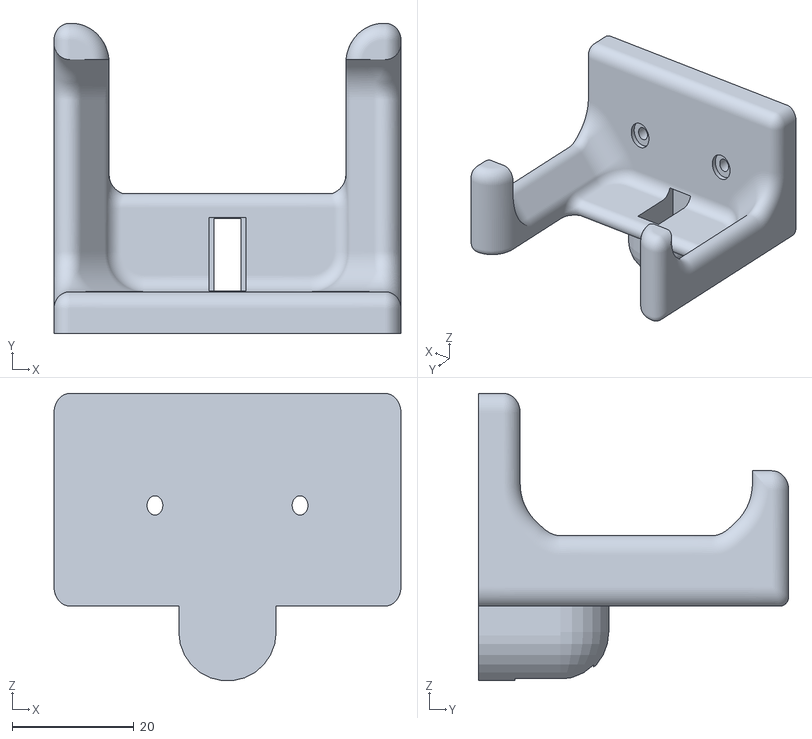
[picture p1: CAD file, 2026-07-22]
cad/stl/zach_hookswitch_cradle.stl
57.0 x 51.0 x 47.2

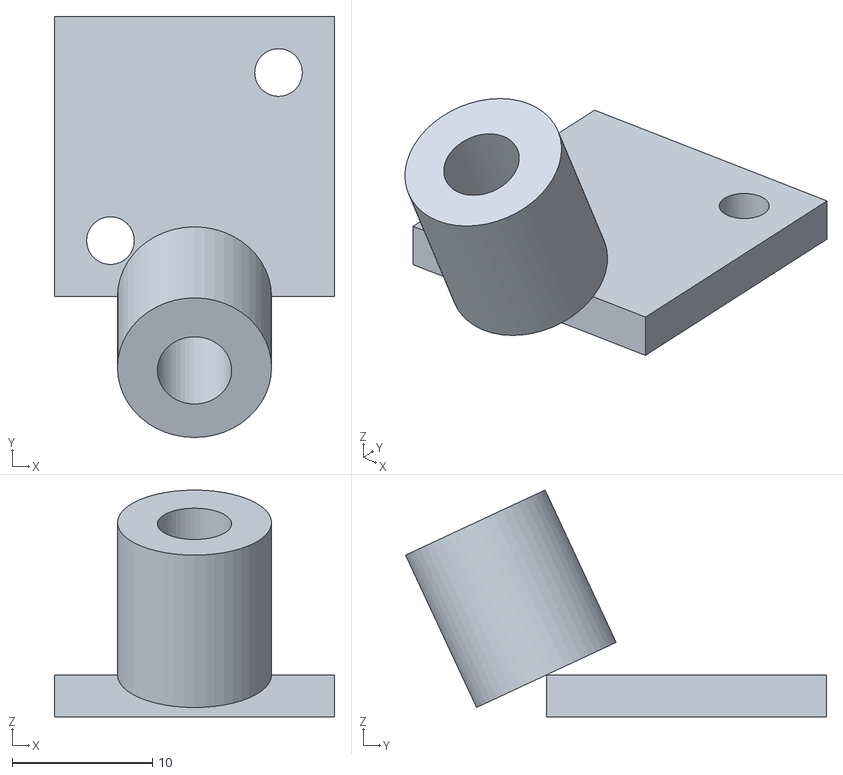
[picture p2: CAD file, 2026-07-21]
cad/stl/ir_blaster_mount.stl
20.0 x 30.1 x 16.2

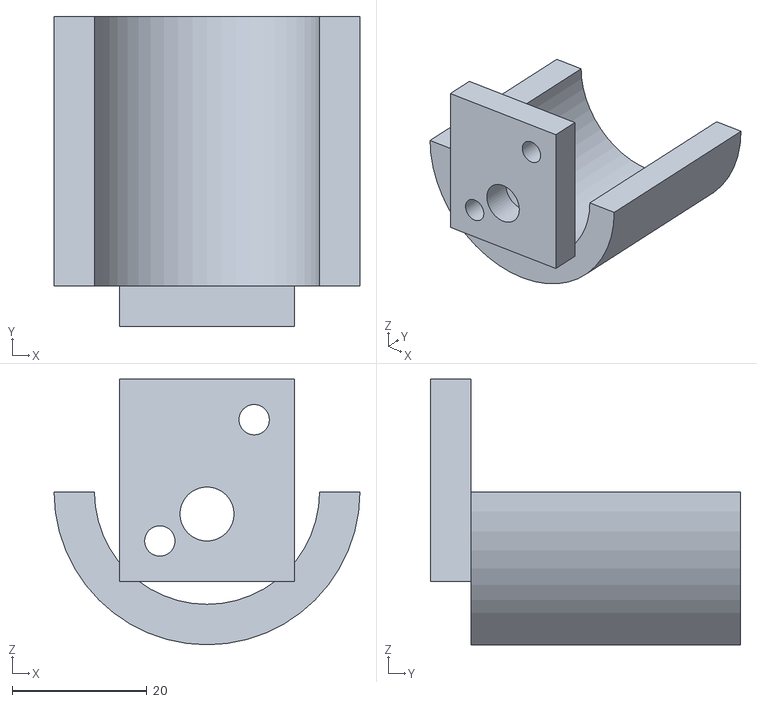
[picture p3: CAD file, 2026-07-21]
cad/stl/wall_hook.stl
45.4 x 46.0 x 39.4

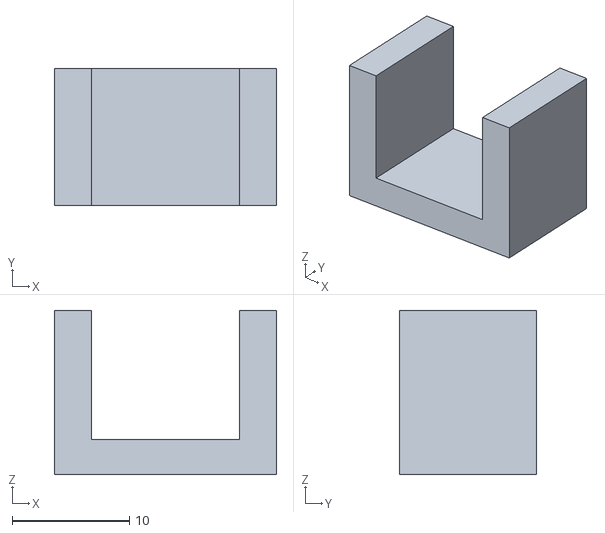
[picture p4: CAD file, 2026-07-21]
cad/stl/switch_mount.stl
18.9 x 11.7 x 14.0

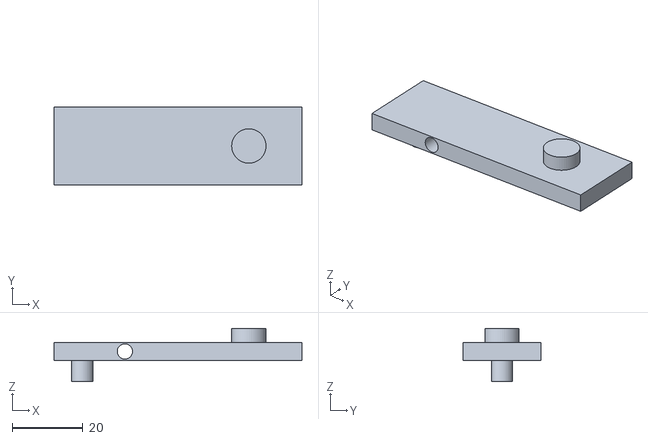
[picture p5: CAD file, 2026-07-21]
cad/stl/hook_lever.stl
70.0 x 22.0 x 15.0

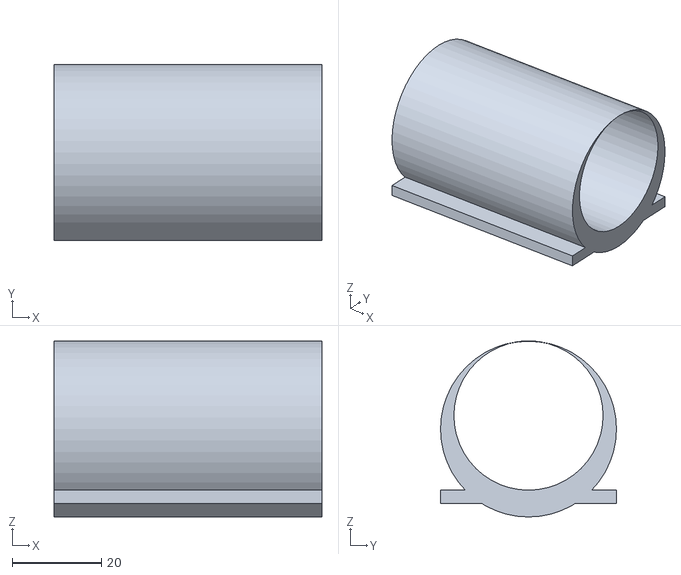
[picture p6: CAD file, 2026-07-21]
cad/stl/phone_saddle.stl
60.0 x 39.4 x 39.4

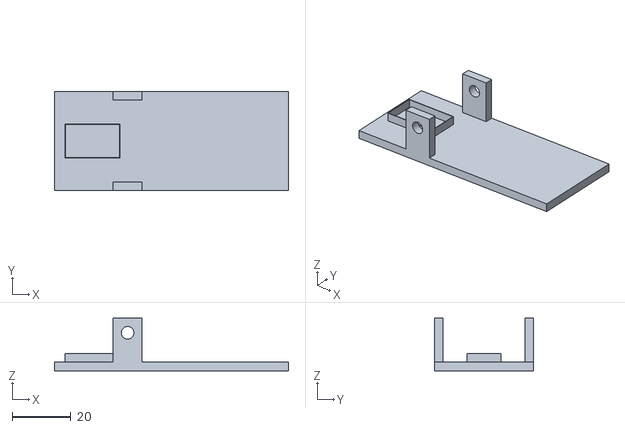
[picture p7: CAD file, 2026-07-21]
cad/stl/cradle.stl
80.0 x 34.0 x 18.0

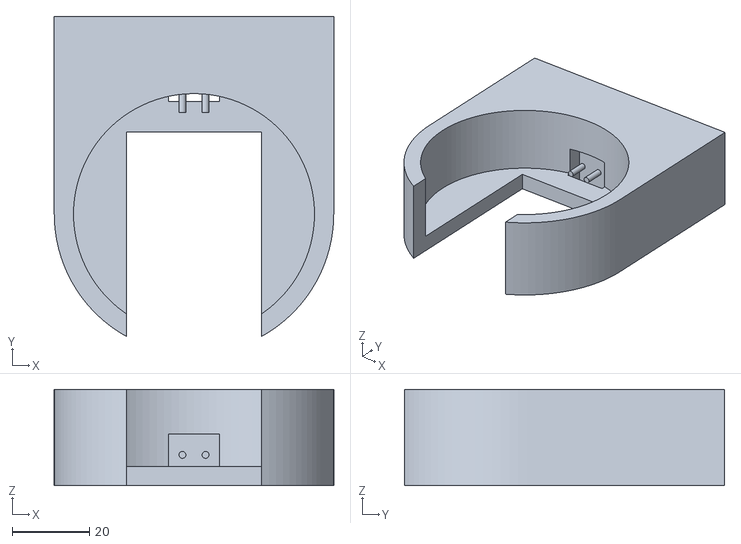
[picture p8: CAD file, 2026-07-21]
cad/stl/gemini_hanging_cradle.stl
72.5 x 83.0 x 25.0

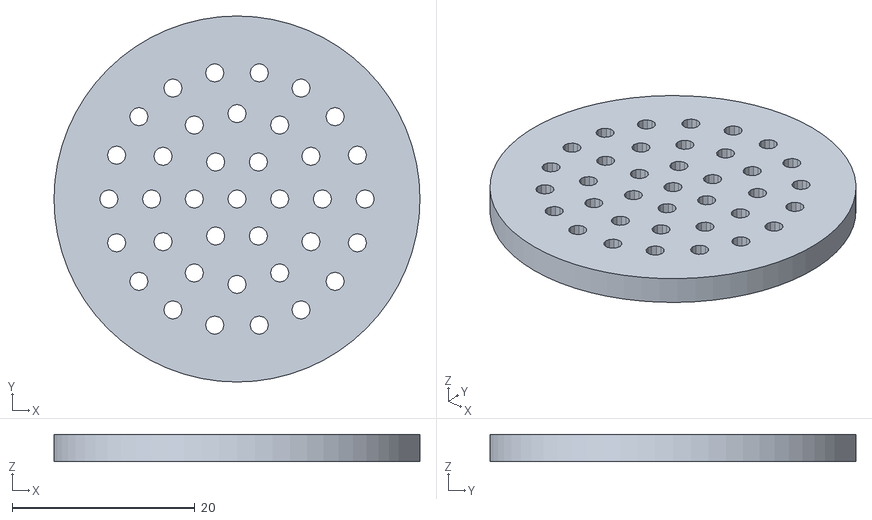
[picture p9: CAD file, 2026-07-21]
cad/stl/earcon_grille.stl
40.0 x 40.0 x 3.00

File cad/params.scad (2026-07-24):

// Shared measurements for the hookswitch assembly (handset / hook / cradle / switch).
// Real caliper measurements taken 2026-07-20 (see CAD-BACKLOG.md) — no
// longer placeholders. switch_screw_d is still a guess (pin/screw size
// wasn't calipered); verify before drilling.

// --- Handset ---
// Measured handle neck width 32.8mm; +0.6mm printer clearance so the
// barrel doesn't bind in the trough (phone_saddle.scad cuts this exact dia).
handset_barrel_d   = 32.8 + 0.6;  // = 33.4
handset_rest_len   = 60;   // length of barrel section that sits in the saddle (not calipered — neck length, adjust if handset sits too shallow/deep)

// GUESS, not calipered (2026-07-24) — full-body handset dims beyond the
// neck above. Zach says the handset "feels standard" in the hand, so
// these are sized off a typical modern corded/cordless handset (same
// ballpark as the earpiece-cup scale already used in
// zach_hookswitch_cradle.scad's imported reference STL). Good enough to
// keep wall_hook.scad/cradle work moving; replace with real numbers from
// cad/HANDSET-MEASUREMENTS.md whenever calipers are actually in hand —
// don't let this comment go stale once that happens.
handset_overall_length = 225;  // GUESS — tip of earpiece to tip of mouthpiece
handset_earpiece_d     = 50;   // GUESS — cup diameter at the ear end
handset_mouthpiece_d   = 45;   // GUESS — cup diameter at the mouth end (typically a touch smaller)
handset_weight_g       = 170;  // GUESS — informs lever spring/pivot friction choice, not geometry

// --- Hook lever (see-saw pressed down by handset weight) ---
lever_length       = 70;
lever_width        = 22;
lever_thickness    = 5;
pivot_pin_d        = 4;    // diameter of the pivot rod/pin (e.g. M4 bolt or steel rod)
pivot_offset       = 20;   // distance from lever's front edge to the pivot axis

// --- Microswitch (measured: 3-pin lever subminiature microswitch) ---
switch_body_w      = 12.9;   // body length (L)
switch_body_d      = 5.7;    // body width/thickness (W)
switch_body_h      = 6.2;    // body height (H), excludes pins & lever button
switch_lever_ext   = 4.1;    // lever extension above body top — clear this in switch_mount_h
switch_mount_hole_spacing = 6.0;  // measured mounting hole pitch
switch_screw_d     = 2.2;        // NOT calipered — guess for M2 self-tap, verify against actual pins

// --- IR blaster (persona/channel-switch signaling, see PHILOSOPHY.md #5) ---
ir_led_d           = 5;    // standard 5mm IR LED
ir_mount_w         = 20;
ir_mount_h         = 12;

// --- Earcon speaker (small dedicated driver for crt-earcon.sh beeps,
// separate from the handset earpiece -- see IDLE-BAIT.md) ---
earcon_speaker_d   = 28;   // typical small round speaker (e.g. 28mm mini driver)
earcon_grille_hole_d = 2;
earcon_grille_hole_spacing = 4;

// --- General ---
wall               = 3;
clearance          = 0.3;  // fit clearance between mating printed parts
$fn                = 48;

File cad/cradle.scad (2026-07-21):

// "cradle" part: the base body. Houses the pivot pin bosses for
// hook_lever.scad and a mounting pocket for switch_mount.scad, positioned
// so the lever's rear boss lands on the switch plunger at rest.
include <params.scad>

cradle_w = lever_width + wall*4;
cradle_l = lever_length + 10;
cradle_h = 22;

// switch_mount's base-plate footprint (must match switch_mount.scad)
switch_mount_w = switch_body_w + wall*2;
switch_mount_d = switch_body_d + wall*2;
socket_lip_h   = 3;      // height of the retaining rim, grips the base plate edge
socket_fit     = 0.3;    // interference: socket opening is footprint minus this

module cradle() {
  difference() {
    union() {
      // base
      translate([-pivot_offset - 5, -cradle_w/2, 0])
        cube([cradle_l, cradle_w, wall]);

      // pivot support walls, one each side, at x=0 (pivot axis)
      translate([-pivot_pin_d/2 - wall, -cradle_w/2, wall])
        cube([pivot_pin_d + wall*2, wall, lever_thickness + 10]);
      translate([-pivot_pin_d/2 - wall, cradle_w/2 - wall, wall])
        cube([pivot_pin_d + wall*2, wall, lever_thickness + 10]);
    }

    // pivot pin hole through both support walls
    translate([0, -cradle_w/2 - 1, wall + lever_thickness + 5])
      rotate([-90, 0, 0])
        cylinder(d = pivot_pin_d + clearance, h = cradle_w + 2);
  }

  // socket that switch_mount.scad's base plate press-fits into (no
  // screws). Position tuned so it's directly under hook_lever's rear
  // boss (at x = -pivot_offset + 8 in lever-local coords, pivot at x=0).
  translate([-pivot_offset + 8 - switch_mount_w/2, -switch_mount_d/2, wall])
    difference() {
      cube([switch_mount_w, switch_mount_d, socket_lip_h]);
      translate([socket_fit/2, socket_fit/2, -0.1])
        cube([switch_mount_w - socket_fit, switch_mount_d - socket_fit, socket_lip_h + 0.2]);
    }
}

cradle();

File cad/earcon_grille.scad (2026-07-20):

// Grille + mount for a small dedicated speaker driving crt-earcon.sh's
// beeps (IDLE-BAIT.md / SIDETONE.md), separate from the handset earpiece
// -- the idea being the CRT itself gets a voice for non-verbal cues
// (beeps, chirps) distinct from anything that only plays through the
// phone. A round hole pattern over a speaker cavity, printable as a
// snap/screw insert into a project box or the CRT chassis.
//
// STATUS: pure speculative geometry -- no speaker purchased, no mounting
// surface measured. Placeholder shape to react to, not print-ready.
include <params.scad>

module earcon_grille() {
  plate_d = earcon_speaker_d + wall * 4;
  difference() {
    cylinder(d = plate_d, h = wall, $fn = 64);
    // concentric rings of small holes -- classic speaker-grille pattern
    for (ring = [0:2]) {
      r = (earcon_speaker_d / 2) * (ring + 1) / 3;
      n = 6 + ring * 6;
      for (i = [0:n-1]) {
        a = i * 360 / n;
        translate([r * cos(a), r * sin(a), -1])
          cylinder(d = earcon_grille_hole_d, h = wall + 2, $fn = 12);
      }
    }
    // center hole too
    translate([0, 0, -1]) cylinder(d = earcon_grille_hole_d, h = wall + 2, $fn = 12);
  }
}

earcon_grille();

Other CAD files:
cad/gemini_hanging_cradle.scad
cad/hook_lever.scad
cad/ir_blaster_mount.scad
cad/phone_saddle.scad
cad/switch_mount.scad
cad/wall_hook.scad
cad/zach_hookswitch_cradle.scad

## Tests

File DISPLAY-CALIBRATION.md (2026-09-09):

# Display calibration: the overscan game

The VM's default graphical output **overshoots** the CRT's visible area
(the tube's bezel/overscan crops the edges of a normal 4:3 signal — this
is completely normal CRT behavior, not a bug in the VM), but forcing an
800x600 mode **undershoots** (leaves the picture smaller than the tube can
actually show, wasting real visible area). Neither raw setting is right;
what's needed is the classic broadcast-TV answer to exactly this problem:
a **safe area** — content deliberately kept inside a margin that's
guaranteed visible regardless of the exact overscan on this specific tube
— plus, if possible, dialing the VM's actual output resolution closer to
right in the first place.

## Two independent levers, don't conflate them
1. **VirtualBox display resolution** (host-level, e.g. `VBoxManage
   setextradata`/guest additions custom mode) — the "real" fix, gets more
   of the signal actually inside the visible tube. **Needs dexter access
   to test** — not buildable this session.
2. **Software safe-margin inset** (this repo, works regardless of #1) —
   every renderer (`crt-pager.py`, `crt-monologue.sh`, the calibration
   pattern itself) insets its content by a configured margin, so even an
   imperfect resolution choice never *clips actual content*, only wastes
   some blank border. This is the one built this session, and it's the
   one that matters more: #1 can only ever get you *close*, given a fixed
   discrete set of resolutions vs. a continuously-variable real tube;
   #2 is what actually guarantees nothing important gets cut off.

## The calibration "game" (a ritual mode, per Chris's framing)
Consistent with `PHILOSOPHY.md` #4 (verbs, not menus): calibration should
feel like a small interactive game played over the handset, not a menu of
numeric settings. The shape:
1. Render a test pattern: a numbered ruler along all four edges, a letter
   in each corner, at the **current** safe-margin guess.
2. Ask, by voice: "can you see the letter in every corner? which ones
   are cut off?"
3. Chris answers by voice ("top right is gone" / "all four are fine" /
   "the whole left edge is cut off"). STT parses this into a per-edge
   cut-off/ok signal.
4. Adjust: any cut-off edge grows its margin (pull content further in);
   any consistently-fine edge shrinks its margin a little (reclaim
   wasted border) — a simple hill-climb, not a search algorithm, because
   the actual physical crop doesn't change between rounds, so a few
   rounds of "grow what's cut, shrink what's fine" converges fast.
5. Repeat until Chris says it looks right, or a round changes nothing
   (converged). Save the result to `~/.crt/display.conf`.
6. Every renderer reads that margin from then on.

## Shipped, and what's still a guess
`bin/crt-calibrate-display.py` (`render_pattern`/`adjust_margins`/
`load_display_conf`/`save_display_conf`, each documented at its own
definition) implements the ritual above; `crt-pager.py` and
`crt-monologue.sh` read the saved margin on every render
(`load_display_margins`/`apply_margins`). Covered by
`tests/test_calibrate_display.py` (the pure functions, including a
deliberately contradictory feedback sequence that must not oscillate
forever), `tests/test_pager.py`, `tests/test_monologue_margin.sh` — all
against synthetic conf files, never a real overscan crop. Two things
remain untested against anything real: `main()`'s interactive loop (needs
a real STT response and a real screen to look at), and the STT-response
parser's phrasing guesses ("top right is gone," "all four are fine") —
same charitable-inference treatment as everything else in
`STT-MECHANISM.md`. Lever #1 (an actual VirtualBox resolution change)
still needs dexter access.

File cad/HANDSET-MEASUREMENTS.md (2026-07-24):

# Handset measurement guide

For Zach, next time the calipers (https://www.amazon.com/dp/B09R84QZ2P) are
actually in hand. One measurement per line in `params.scad` — take it,
report the number (or edit `params.scad` directly), done. No need to do
all of these in one sitting.

## Already real (2026-07-20, do not re-measure unless something changed)

- `handset_barrel_d` — neck/handle diameter, where the hand grips. 32.8mm.
- switch body / hole pitch — see `params.scad`'s microswitch block.

## Still a guess (2026-07-24) — `handset_overall_length`, `handset_earpiece_d`,
## `handset_mouthpiece_d`, `handset_weight_g`

Where to put the calipers/scale:

```
  earpiece                neck (measured)              mouthpiece
   ___                    ___________                     ___
  /   \                  /           \                   /   \
 | (A) |----------------| ===(D)=== |------------------| (B) |
  \___/        (C)        \_________/                    \___/
    ^                          ^                             ^
 ear cup dia.            handset_barrel_d              mouth cup dia.
 measured here           already measured here         measured here
 = handset_earpiece_d    (this is the "neck" you        = handset_mouthpiece_d
                          already calipered 2026-07-20)

  |<---------------------- (C) full length ---------------------->|
                    = handset_overall_length
```

- **(A) `handset_earpiece_d`** — caliper the widest point of the earpiece
  cup (the end that goes against your ear), straight across, outer
  diameter (outside of the plastic, not the speaker grille holes).
- **(B) `handset_mouthpiece_d`** — same, at the mouthpiece end. Often a
  touch smaller than the earpiece end; measure it separately, don't
  assume symmetry.
- **(C) `handset_overall_length`** — tip of earpiece cup to tip of
  mouthpiece cup, in a straight line (not following the curve of the
  handle) — this is what a tape measure or a long caliper gives you
  laid flat on a table next to the handset.
- **(D)** already done — `handset_barrel_d`, the neck/grip diameter. No
  action needed, just shown here for orientation.
- **`handset_weight_g`** — put the whole handset (cord unplugged if it
  detaches) on any kitchen/postal scale. Doesn't affect any geometry
  directly right now, only informs how stiff a return spring the
  see-saw lever needs — low priority, skip if the scale isn't handy.

## After measuring

Edit the four `GUESS` lines in `cad/params.scad`'s "full-body handset
dims" block, delete the word GUESS from each comment, then
`./export_stl.sh` to re-render anything downstream (currently only
`wall_hook.scad` derives from these; the hookswitch lever/saddle assembly
only needs `handset_barrel_d`, already real).

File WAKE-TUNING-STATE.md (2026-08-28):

# Wake-word self-tuning state

Living journal for the autonomous wake-word judge (`bin/crt-wake-judge.py`,
2026-07-21, Zach's direct ask: "call claude, if it got ignored, tweak. if
it sees a lot of attempts to wake it failing... tweak. but also be
available to help"). Every wake event (exact wake word, exact wake-pool
match, or fuzzy cluster match) fires a background, rate-limited `claude -p`
call with the triggering text + match details. That judge call decides
whether the wake was good or bad, and may edit:

- `~/.crt/wake-pool-dict.txt` -- remove a specific bad word
- `~/.crt/wake-tuning-config.json` -- the live per-source fuzzy cluster
  minimums / close-ratio (overrides `crt-wake-pool.py`'s
  `DEFAULT_CLUSTER_MIN_BY_SOURCE`/`FUZZY_CLOSE_RATIO` code defaults)
- this file's Judgment log -- ONLY when a call moves one of the two knobs
  above (crt#79); every event otherwise also lands in
  `~/.crt/wake-judge-events.log`, capped, for pattern history

**Ground truth signal for "was this wake genuinely wanted":** did a real
follow-up utterance arrive and get dispatched within the arm window
(`consume_arm_with_followup` fired), or did the window time out with the
follow-up never coming (`check_arm_timeout` fired with nothing to send,
or with only a leftover fragment nobody ever continued)? A consumed
follow-up is strong evidence the wake was wanted; a timeout is evidence
it wasn't -- but a SINGLE timeout should never trigger a tweak on its own
(could just be Zach getting distracted after a genuine wake, or leaving
mid-thought) -- look for a *pattern* before acting, per Zach's own
framing ("a lot of attempts... failing").

**Starting values (2026-07-21, before any live tuning data):**
- `FUZZY_CLOSE_RATIO`: 0.72
- `cluster_min_by_source`: `{"dict": 2, "book-title": 4}`
- Reasoning: a live session's actual pool was found to be ~90% noisy
  book-title words (confederacy, dunces, lolita, cinema, etc. -- nobody
  says these to address a console), which false-armed on ordinary
  conversation ("Confederacy!" armed and silently ate 8s with no
  follow-up). Book-title words need much stronger corroboration
  (originally 2, raised to 4) than deliberately hand-seeded dict words.

## Judgment log

Entries land here only on an actual tuning change (crt#79); older
per-event entries were reaped to `vault:crt/wake-judge-log-20260825.md` --
this file is inside a shrink-only prose ratchet.

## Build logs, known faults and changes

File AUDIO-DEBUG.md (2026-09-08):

# Audio capture debugging — the "stops detecting" bug

The recurring failure: STT works, then mid-session the mic signal goes quiet
with the ALSA mixer still correct — capture goes **stale** when the device is
opened and closed per utterance, or when a second reader starves the primary.

Written against the VirtualBox guest this project used to run on, and kept
because the failure shape outlived the host: the console runs on potato now,
and Approach B is what it runs.

## Status legend
`[code]` implemented, unverified on the console · `[partial]` scaffolded · `[idea]` sketch only

---

## Approach A — capture watchdog (auto re-open) `[code]`
`bin/crt-capture-watchdog.sh`

The narrowest fix for the exact reported symptom. A background daemon holds one
continuous reader on the mic and computes a rolling level. If the signal stays
**flat** (near-zero peak variance) for `CRT_WD_FLAT_SECS` — i.e. the capture has
gone stale, not merely silent — it declares the device dead and **recovers**:
kills stale `arecord`/`sox` holders, re-asserts the mixer (Input Source=Line,
Capture 100%), and (opt-in) restarts the `stt` tmux window so `stt-feed.sh`
re-opens a fresh capture. Logs every event to `~/.crt/watchdog.log` so the
failure cadence can be characterized.

Test: run alongside the normal console; force staleness (let it idle, or toggle
the VBox audio controller) and confirm it recovers within a few seconds.

## Approach B — single-reader console (eliminate dsnoop) `[promoted, now the default]`
`bin/crt-stt-solo.py` extended with `CRT_STT_SINK=claude`, wired into `bin/crt-console.sh`

Root-cause structural fix: the staleness class that comes from *multiple readers*
(meter + stt-feed both on dsnoop) simply cannot happen if exactly **one** process
ever touches the mic. `crt-stt-solo.py` already is that one process for STT-only;
extending it to also type into the Claude tmux pane makes it a drop-in
replacement for the whole stt-feed + dsnoop-meter stack.

**Verified live 2026-07-19/20** (real handset session on the retired VM, crt#162) and, as of
2026-07-20, promoted into `bin/crt-console.sh` itself as the actual boot
default (see that file's own comments, and `vault:crt/HANDOFF-20260829.md`'s
"what's running" section) — `bin/crt-console-solo.sh` is no longer the only way to get this,
it's just a thinner standalone variant of the same idea. `stt-feed.sh` +
`crt-levels.sh` still exist (used by `CRT_SECRETARY`/stdout debug modes) but
are no longer what boots by default.

## Approach C — proactive keep-alive heartbeat `[code]`
Built into Approach A's watchdog as `CRT_WD_KEEPALIVE=1`

Rather than only reacting to staleness, periodically nudge the emulated ADC so it
never goes cold: the watchdog's single always-open stream is itself a keep-warm;
with keepalive on it additionally re-asserts the mixer every `CRT_WD_KEEPALIVE_SECS`
even when the signal looks fine. Cheap insurance; may make A's reactive path rare.

## Approach D — audio doctor / liveness telemetry `[code]`
`bin/crt-audio-doctor.sh`

Research instrument, not a fix. Two modes: `check` (one-shot health report — lists
cards, the Input Source/Capture mixer state, and a 3 s live RMS/peak sample, exit
non-zero if dead) and `monitor` (append a timestamped RMS/peak sample every N s to
a CSV, so a whole session's capture behaviour can be plotted afterwards). The goal
is to answer the open question: does staleness correlate with idle time, with
utterance boundaries, or with a fixed interval? That determines which of A/B/C is
the real fix vs a band-aid.

Test: `bin/crt-audio-doctor.sh check`; `bin/crt-audio-doctor.sh monitor` during a
session, then inspect `~/.crt/liveness.csv`.

## Approach E — capture-backend variants `[idea]`
Config-only alternatives to try when A–D don't fully settle it:
- **arecord buffer tuning**: `--buffer-size`/`--period-size`/`-F` to avoid xruns
  that may trigger the VBox stall; try larger buffers.
- **Different PCM path**: `hw:0,0` vs `plughw:0,0` vs a fresh `dsnoop`/`dmix`
  rate-matched to 16 kHz to avoid the plug plugin's resample churn.
- **PipeWire/`parecord`** as the capture source instead of raw ALSA, letting the
  guest audio server own the device lifecycle.
- **VirtualBox audio backend**: try `--audiocontroller hda` vs `ac97`, and the
  host audio driver, from the dexter side (VBoxManage). Host-side, needs dexter.

These are enumerated so an overnight job (or a VM session) can pick one, wire a
toggle, and measure with Approach D — not to be all built blindly.

## Approach F — streaming / rolling-window STT `[partial]` (nightly batch: research + prototype)

Right now whisper.cpp runs **batch per VAD-cut utterance**: it waits for the
phrase to end, transcribes the whole clip once, and never revises. Web/streaming
ASR instead emits partial words and *revises them as more audio + language-model
context arrive* (online transducer/attention decoders committing late). That
self-correction is what makes browser dictation feel live.

Whisper isn't natively streaming, but two routes approximate it:
- **whisper.cpp `stream`** example — sliding window, partial results (crude; not
  even built here yet — `make stream` in whisper.cpp).
- **LocalAgreement rolling window** (à la `whisper_streaming`): re-decode a
  growing buffer every ~0.5 s and only *commit* a word once two consecutive
  windows agree on it, revising the uncommitted tail. Lower latency + context
  self-correction.

**Scope for the nightly batch (code only, no VM):** research both, and prototype
the LocalAgreement approach as a NEW opt-in engine (e.g. `bin/crt-stt-stream.py`)
alongside `crt-stt-solo.py` — do NOT replace the working batch engine. Wire the
same sinks (stdout / claude) and the same hallucination + noise filters. Leave a
clear note on CPU cost (re-decoding is much heavier than batch) since this runs
on a VM. Honest caveat in code: not hardware-verified.

**Reality check (already assessed 2026-07-19):** for a short-command console,
streaming mainly buys latency and long-form self-correction; it will NOT fix
noise-driven hallucinations — that's what the highpass/noisered filter (now in
crt-stt-solo.py) and a better VAD (Silero) are for. So treat F as a
feel/latency upgrade, not the noise fix.

**Prototype built (2026-07-19 nightly batch):** `bin/crt-stt-stream.py` +
`bin/crt-stt-stream-view.sh`. Same VAD/capture/denoise/hallucination-filter/
log conventions as `crt-stt-solo.py`; the new part is `local_agreement_commit()`
— every `CRT_STREAM_INTERVAL` (default 0.7s) it re-decodes the whole
utterance-so-far and commits the prefix that agrees with the immediately
prior decode (LocalAgreement-2), printing committed words plain and the
uncommitted tail dimmed. On utterance end it does one more full decode and
that — not the partial trail — is what actually reaches the log/claude sink,
so accuracy of the *final* result is unaffected either way; only the live
feel changes. Verified so far: syntax/compile clean, `local_agreement_commit`
unit-tested (agreement + disagreement-halts-commit cases), and `transcribe()`
smoke-tested against a real local whisper-cli + tiny.en model on the dev box
(silence in, empty string out, no crash). **NOT verified:** live mic
behavior, whether 0.7s ticks feel responsive vs. janky, or whether the
guest's CPU cap (see COST WARNING in the file's header) makes this unusably
slow without `CRT_WHISPER_SERVER` pointed at dexter — needs a VM/handset
session with real speech.

---

## The handset "0.1x above baseline" measurement should be re-run (2026-07-25)

The 2026-07-23 backlog entry recorded the strongest audio finding this
project has: a tone played on the handset device (`plughw:1,0`) while capture was
running showed **0.1x above baseline** in the recording, read as "this USB
adapter cannot reliably play and record at once — a hardware/driver limit,
not a routing bug." The whole CTL-file capture-duck feature (cycles 3, 4 and
`fe46ac1`) was built on that reading, and stability-bar item 2 is waiting on a
re-run of the tool to confirm it.

`bin/crt-earcon-loopback-test.py` could not have established it. Until
2026-07-25 it sent sox's and aplay's exit status **and** stderr to
`/dev/null`, so "played, and the mic could not hear it" and "never played at
all" produced byte-identical output and it always reported the first. Those
two indict opposite things — a USB adapter versus a device name — and this
project's audio history is overwhelmingly the second (`plughw:0,0` with no
capture stream, the dead dexter earcon URL, the `:8992` default).

The tool now has a third verdict (`INCONCLUSIVE`) and exits 3 for it, so the
re-run answers the question either way. **Nothing here overturns the original
reading** — 0.1x is also exactly what a working-but-deafened adapter looks
like, and the tone did register on the TV path in the same session, which
argues aplay was working at least there. It is one command's worth of
uncertainty that no longer has to be carried:

    python3 bin/crt-earcon-loopback-test.py handset ; echo "exit $?"

`exit 3` means the measurement never happened and the finding is unsupported.
`exit 1` with a ratio near 0.1 means the finding stands and the duck is right.

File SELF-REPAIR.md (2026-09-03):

# Self-repair — potato's nightly autonomous pass

Scoped with Zach, and `potato`-specific: the Raspberry Pi that replaced the
crt-vm guest as the console. Mirrored nowhere else.

## What "self-repair" means here (Zach's answers, verbatim scope)

- **Fully autonomous self-editing** — potato's `claude` instance may edit
  its own scripts/configs live, without a human reviewing each change
  first. This is a real escalation from `--permission-mode acceptEdits`
  (the crt-vm default) to `bypassPermissions` (already set via
  `CRT_CLAUDE_ARGS` in potato's `~/.bash_profile`, 2026-07-22).
- **Trigger: nightly**, scheduled — same shape as the existing nightly
  batch job (`schedule/crt.conf` in `hf7y/scheduler`, whose procedure is
  `schedule/_run-procedure.md`), not event-driven or continuously running.
- **Sensitivity target: STT/audio first** (`CRT_VAD_THRESHOLD`,
  `CRT_VAD_START_CHUNKS`, `CRT_VAD_TRAIL`, `CRT_VAD_MAX/MIN`,
  `CRT_VAD_PREROLL` — see `bin/crt-stt-solo.py`'s own env-var block — plus
  the STT_GATE/STT_CONFIDENCE knobs in `vault:crt/STT-GATE.md`/`STT-CONFIDENCE.md`),
  but Zach's explicit instruction: **"maximally aggressive as long as it
  uses git right"** — read as license to tune broadly, not just audio,
  provided the git-commit discipline below is never skipped.
- **Safety rail: commit + surface, not approval-gated.** Every change
  must land as a git commit (so revert is always one `git revert`/`git
  reset` away — this is the actual point, per Zach: "I just want that
  autonomous unit to be able to revert any major changes"). Zach
  explicitly deferred the "surface a summary" half (push to a
  service-user-owned remote, reporting) to the service-user setup —
  see "Not yet built" below.

## What's built tonight

- `~/crt` on potato is its own local git repo (`git init`, not connected
  to mandark's remote yet — see "Not yet built"). First commit is the
  as-deployed snapshot, the revert baseline.
- `bin/crt-self-repair.sh` — the nightly wrapper. Does NOT trust the
  `claude -p` invocation to remember to commit: it force-commits
  before AND after the run regardless of what Claude itself did, so a
  crash/timeout mid-run still leaves a clean revertible history. Logs to
  `~/reports/crt-self-repair/<date>.log` on potato itself (not yet synced
  anywhere off-box — see below).
- `systemd/crt-self-repair.timer`/`.service` — nightly, potato-only unit,
  deliberately not installed by the shared `install.sh`. By hand on potato:
  `sudo cp systemd/crt-self-repair.{service,timer} /etc/systemd/system/ &&
  sudo systemctl enable --now crt-self-repair.timer`.

## Not yet built (tonight was explicitly base-level only)

- **Any off-box visibility into what potato changed.** Commits are
  currently local-only. Zach: "we have the existing /srv/ situation to
  make that possible, though not sure if ssh is a blocker... save this
  for the service user" — i.e. the actual surfacing mechanism is designed
  together with the service-user work (goal 2 of tonight's ask), not
  built yet. Until that lands, reviewing potato's self-edits means SSHing
  in and reading `git log`/the report log directly.
- **Push access anywhere.** Potato's git repo has no remote configured.
  Explicitly scoped as a separate, bigger decision from local revert —
  see the assistant's own reasoning in-session: local revert doesn't need
  push access at all; push access is a shared-repo blast-radius question,
  deliberately deferred to the service-user identity (modeled on
  `svc-vaporwave`, see `HANDOFF.md`), likely pull-only at first per Zach's
  "right now maybe it's just pull."
- **Any tuning of the actual VAD/gate numbers.** Tonight only wires the
  mechanism (nightly trigger + forced-commit safety net) — the directive
  text handed to `claude -p` each night is what actually does the tuning
  work, and it hasn't run yet (potato was unreachable — mid-physical-move
  — for the rest of this session).
- **Mirroring any of this anywhere else.** Explicitly potato-only.

## Directive text (what the nightly `claude -p` run is actually told)

See `bin/crt-self-repair.sh`'s own `PROMPT=` variable — kept in the script
itself, not duplicated here, so there's exactly one place to edit it.

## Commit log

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2026-07-19 STT noise fix + streaming approach note
    - crt-stt-solo.py: opt-in highpass + noisered + normalize sox chain
    (CRT_HIGHPASS/CRT_NOISERED_PROF/CRT_NOISERED_AMT) to tame room/AC noise
    that makes whisper hallucinate; drop fully bracket/symbol-wrapped sound
    tags ('(metal clanging)', '[BLANK_AUDIO]', '*applause*').
    - AUDIO-DEBUG.md: add Approach F (streaming / LocalAgreement rolling window)
    scoped for the nightly batch to research + prototype as a new opt-in engine.
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2026-07-19 Wire STT into the actual claude pane; note noisy-room context + display control
    - CLAUDE.md: tells the in-VM claude instance it's receiving STT from a
    physically noisy room (expect a higher error rate, infer charitably), that
    it can use ANSI color/style on this real terminal, and to keep a running
    self-correction log at ~/.crt/stt-corrections.md so its inference improves
    over time instead of re-solving the same mis-hears
    - crt-stt-solo.py: STT text now always logs to ~/.crt/stt.log regardless of
    on-screen behavior; on-screen scrolling print is now gated by
    CRT_STT_DEBUG_PERSIST (default off) -- raw STT should only flash briefly
    to mask recognition errors, not linger, per today'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
2026-07-20 STT mission doc, mechanism reference, redraw-based ephemeral monologue
    - CLAUDE.md: reframes the in-VM claude's top priority as actively improving
    STT inference over time (building its own correction dictionaries/
    utilities, asking targeted diagnostic questions about garbling patterns),
    not just passively correcting each utterance
    - STT-MECHANISM.md: new -- explains the actual capture/VAD/denoise/whisper
    pipeline (dsnoop single-reader capture, peak-based VAD with a trail-clip
    failure mode, sox denoise chain that can soften sibilants, local vs.
    network whisper, the hallucination filter) so claude can reason about
    *why* a transcription got garbled instead of treating it as a blac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
2026-07-20 CLAUDE.md: playful tone + self-documenting reboot continuity
    - New "Make it playful" section -- STT optimization should feel like a
    character figuring out a noisy room, not a QA harness; diagnostic
    questions can be part of the fun.
    - New "Document yourself for next boot" section -- keep
    .claude/SESSION-STATE.md updated as it works (not just at the end) so a
    fresh instance after a restart/crash can pick up where it left off; read
    it first on startup, before STT-MECHANISM.md.
    - Sent both this update and a live follow-up (proactively prompt a test
    phrase on screen, then respond once someone actually speaks) into the
    currently-running claude session directly via tmux send-keys, so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
2026-07-20 Bridge claude's actual replies into the pretty-print pane
    crt-claude-bridge.py tails claude's own session transcript (JSONL, the
    standard Claude Code format) and mirrors assistant text replies into
    ~/.crt/thoughts.log -- window 1's ephemeral pretty-print display
    (crt-monologue.py) now shows claude's real responses instead of only my
    separate external narration. Tails the transcript file directly rather than
    screen-scraping the tmux pane (structured, robust to UI chrome). Verified
    end-to-end live: sent claude a test message, its reply appeared in
    thoughts.log and rendered correctly in the window 1 pane within ~8s.
    Running in a new hidden tmux window ("bridge").
2026-07-20 Idle-bait workflow, earcons, sidetone design, philosophy, gallery/payphone RFPs
    Design pass: idle-bait job-report/blocker surfacing tied into the
    scheduler's existing report/question convention (IDLE-BAIT.md), a
    five-tone earcon vocabulary (crt-earcon.sh), sidetone investigation that
    surfaced a real architecture question about handset audio routing
    (SIDETONE.md), seven named interface principles (PHILOSOPHY.md), and
    design briefs for the gallery and payphone installation concepts from
    PARKING-LOT.md. Also fixes crt-announce.sh's stale TV device string and
    adds crt-report.sh/crt-idle-teaser.sh as the stopgap plumbing that makes
    idle-bait have real content today. Nothing hardware-verified this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
    [earcon_grille.scad, ir_blaster_mount.scad, params.scad]
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2026-07-20 Vision pass: supervisor playbooks, calibration game, sideband tone, VM job spec
    Offline-buildable/testable work: hookswitch debounce fix, playbook-based
    secretary (crt-secretary.py), overscan calibration game, ambient sideband
    presence tone, expressive-tone taxonomy, and a design+spec for a
    VM-resident hardware-check job (not installed, no VM access). 56-check
    offline test suite. Redirects FOCUS.md's "Now" to offline-safe work since
    the existing STT items are VM-blocked and unreachable by the unattended
    batch.
2026-07-20 Idle timeout (not clock-based quiet hours), pure-code morning-report presenter
    Idle-bait now gates on a screensaver-style activity timeout across
    stt.log/sideband-state mtimes instead of a fixed hour window, per
    direction. Also: crt-present-morning-report.py parses morning-report.sh's
    own stdout with zero Claude calls, wired as a crt-secretary.py playbook,
    with a defensive timeout since morning-report.sh was independently found
    to hang. MORNING-REPORT-PRESENTATION.md documents the screen/printer
    mapping and what the scheduler side would need (standardized per-project
    headline field) for this to work well.
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2026-07-20 Add calibrate playbook to crt-secretary.py
    "calibrate the display" runs crt-calibrate-display.py show (single-shot
    pattern render, not the interactive multi-round game -- that needs real
    voice back-and-forth and doesn't fit the one-shot playbook shape).
    124 offline checks green.
2026-07-20 Fold BLOCKERS.md answers into project docs
    Real direction given on nearly every open blocker: RF->IR correction
    for the TV power-on trigger, HDMI-to-RF modulator already owned (housing
    is the real remaining blocker, not sourcing), persona-channel switch +
    IR blaster parts sourced, payphone quarters-for-testing/token-conversion
    framing resolves the legal question, video-cast scoped (VLC-based,
    file-share + streaming, medium priority) as a new VIDEO-CAST.md, gallery
    possibilities writeup (autonomous Pis vs POTS wiring) added to
    RFP-GALLERY.md, MIDI direction noted in FOCUS.md (dexter-side dev, eventual
    bare-metal Linux merge).
2026-07-20 Heads-up: check scheduler's current state before more morning-report presenter work
    Scheduler had a significant redesign session 2026-07-20 -- the
    .claude/** permission gate this project's own
    MORNING-REPORT-PRESENTATION.md ran into is root-caused and fixed, and
    bin/morning-report.sh (the interface being parsed) is very likely
    being retired in favor of a real, already-working bin/scheduler CLI,
    not just patched for the hang bug already reported. Flagging before
    more work goes into the presenter against a shape that may not be the
    long-term target.
2026-07-21 Prototype LocalAgreement streaming STT (Approach F)
    New opt-in engine, doesn't touch the working crt-stt-solo.py batch
    pipeline: re-decodes the growing utterance buffer every ~0.7s and commits
    words once they agree with the prior decode, so partial text appears
    while still speaking instead of only after the VAD trail. Final result
    still comes from one full-buffer decode, so accuracy is unaffected --
    only the live feel changes.
    local_agreement_commit() unit-tested; transcribe() smoke-tested against
    a real whisper-cli + tiny.en model (silence in, empty out, no crash).
    Not verified against live mic/speech or the VM's CPU budget -- that
    needs a handset session, noted in AUDIO-DEBUG.md.
2026-07-21 VM hardware check: replace claude -p with a plain script
    Every check the job runs (test suite pass/fail, device presence, exit
    codes) is mechanical -- no judgment call actually needed an LLM. Zach:
    "can't this be done without claude?" -- yes. bin/crt-vm-hardware-check.sh
    replaces .claude/commands/vm-hardware-check.md; the systemd service now
    execs the script directly instead of `claude -p --permission-mode
    acceptEdits`. Cheaper, deterministic, no unattended-agent trust surface
    on hardware the household uses daily.
2026-07-21 Wire the proven live console layout into crt-console.sh, record the incident
    The 2026-07-19 live session hand-assembled a better setup in extra tmux
    windows -- crt-stt-solo.py (single mic reader) + crt-claude-bridge.py +
    crt-monologue.py (pretty-printed claude dialogue, window 1) -- and it ran
    well all evening. It was never wired into crt-console.sh (the actual
    autologin entrypoint), so a routine VM reboot the next night silently
    reverted to the old default (stt-feed.sh + a separate meter pane) with no
    record beyond ps aux archaeology.
    Wired the proven layout directly into crt-console.sh's own code, not just
    documented -- a doc is easy to skip, code that runs on every boot isn't.
    Updated HA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
2026-07-21 Add crt-vm-watchdog: periodic heal pass for the live tmux STT pipeline
    Autologin only refires when the whole tmux session dies; it never
    catches a single window's process (crt-stt-solo.py/crt-monologue.py/
    crt-claude-bridge.py) dying quietly into its `; exec bash` fallback.
    This installs a 5-min systemd timer that checks each window's expected
    process and respawns/recreates it as needed, without touching window 0
    (Claude Code itself) so a real crash there stays visible on the CRT
    instead of being silently papered over.
    Also records dexter's new crt-whisper-server Scheduled Task (auto-start
    on logon, previously manual Start-Process only) in HANDOFF.md.
2026-07-21 Add Book Game vision: barcode-scan trivia as structured STT training data
    Scan ISBN -> 2-option question about the book -> spoken answer graded
    exact-ish against the two known options -> every (expected, heard)
    mismatch logged as labeled training data, book registered locally,
    stretch LCC label printing. Registers the offline-safe half (lookup,
    question gen, grading/logging, registry, LCC computation) in FOCUS.md
    for the nightly-batch tier; hands-on hardware phase stays deferred.
    Also records 2026-07-21 blockers: scanner needs a dexter-side network
    bridge like the whisper server, not raw USB passthrough; the VM's
    audio-meter tmux pane may not be surviving reboot; and parks the
    longer-term a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
2026-07-21 Verify STT/meter pane survives reboot; clear that book-game blocker
    Checked live on crt-vm after this morning's 04:25 boot: all 4 tmux
    windows present, stt meter live, crt-stt-solo.py running and wired
    correctly. Zach's flagged concern (meter pane not spawning on reboot)
    did not reproduce this time -- updates BOOK-GAME.md's blocker entry
    from "unconfirmed" to a checked single data point, not fully closed.
2026-07-21 Demote label printing to display-only for v1 (Bluetooth-through-VM risk)
    Printer identity settled (Phomemo M02, known-working via bin/catprint)
    but it's Bluetooth, likely the same passthrough-through-VM problem
    class as the scanner/MIDI USB issues, unverified either way. v1 just
    displays the computed LCC number on the CRT instead of printing a
    label -- avoids debugging a third passthrough route before the core
    game exists. Physical labels revisited later.
2026-07-21 Fix scanner forwarder, confirm live scan, make both sides persistent
    - Rewrote dexter-scanner-forward.ps1's RawInput message filter as a
    single Add-Type C# block -- the PowerShell-class version couldn't
    parse (a class can't derive from a type Add-Type loads later in the
    same script, since class definitions resolve before any statement runs).
    - Load-tested against a real scan: confirmed working end to end.
    - crt-vm: installed crt-scanner-feed.py as a systemd service (enabled,
    survives reboot). Hit and documented a port-conflict gotcha where an
    ad hoc test process silently starved the systemd-managed one.
    - dexter: registered a Scheduled Task (CrtScannerForward, at-logon
    trigger) s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
2026-07-21 Shadow claude with a mouse-tracking-reset wrapper (segfault fix)
    Investigated the repeat Bun segfault-on-launch: a crashed Bun/Ink TUI
    never runs its own mouse-tracking-disable sequence, so the terminal
    keeps feeding raw mouse-motion escape bytes to whatever reads next --
    plausibly flooding the next claude launch's input parser. bin/claude
    resets mouse tracking then execs the real binary by hardcoded path.
    Wired into crt-console.sh's PATH (covers scripted launch + manual
    relaunch after a crash) and bash_profile.append (covers a fresh
    independent SSH login too).
    Not yet deployed to crt-vm -- holding for another agent's in-flight
    push to land first. See HANDOFF.md for full investigation notes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
2026-07-21 Add scanner keystroke suppression to dexter-scanner-forward.ps1
    Live bug found 2026-07-21 (Zach): RawInput only observes input, it never
    blocks it -- the scanner's keystrokes were still reaching whatever had
    focus on dexter (the VirtualBox GUI window, which IS the CRT display, so
    avoiding focus isn't an option) in parallel with being forwarded over
    HTTP. Not cosmetic for this app specifically: window 0 of the tmux
    session is a live Claude Code agent, so an unsuppressed scan could type
    a raw ISBN into a real prompt or blindly answer a permission prompt.
    No serial/COM-port mode available on this scanner (checked the manual),
    so ruled out the cleaner device-level fix. Added a WH_KEYBOARD_LL
    lo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
2026-07-21 Fix dexter-scanner-forward.ps1: TickCount64 doesn't compile here
    Add-Type was failing to compile (Environment.TickCount64 not found in
    this dexter's PowerShell 5.1 Add-Type target), and the huge compiler
    error dump was hanging the whole process forever writing to a
    Start-Process-redirected pipe nobody was draining -- it looked "running,
    no errors" in every process/log check because the log file itself never
    got flushed. Every real scan since the suppression feature was added
    leaked straight through to whatever had focus (confirmed live: a scan
    landed as raw text in the live claude pane, burning an actual agent turn
    on a web search for the ISBN). Swapped to Environment.TickCount (int,
    availab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
2026-07-21 Document dexter-side scanner capture as a dead end; plan the pivot
    Long debugging session: dexter-scanner-forward.ps1 never actually
    caught a real scan across three launch mechanisms (SSH-spawned
    Start-Process gets killed on session close; Task Scheduler persists but
    logged zero raw-input events in a live debug test; disabling VirtualBox
    keyboard auto-capture didn't help either). Also found and fixed a real
    bug along the way (Environment.TickCount64 doesn't compile on this
    dexter's PowerShell, silently hanging the process behind a healthy-
    looking process list) before concluding the whole approach is a dead
    end, not just under-debugged.
    Confirmed instead: the scanner's raw keystrokes reliab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
2026-07-21 Wire CRT_STT_SINK=secretary: route STT through crt-secretary.py
    Closes PARKING-LOT.md's "Local-first STT routing" plan -- crt-stt-solo.py
    can now fire-and-forget each gated utterance to crt-secretary.py's
    local-playbook-first router instead of typing straight into Claude's
    tmux pane. Non-blocking (Popen), so the capture loop never stalls on a
    live Claude round-trip. Control keystrokes (yes/no/enter/etc) still go
    straight to tmux unchanged, same as the claude sink always did.
    Opt-in -- SINK still defaults to claude, not the new boot default until
    a human runs secretary mode live against real transcriptions.
    5 new tests (tests/test_stt_secretary_sink.py), full suite green.
2026-07-21 Implement the stdin-scan pivot (hands-on agent's confirmed-live fix)
    crt-book-console.py now reads scans directly off its own stdin, in
    addition to tailing ~/.crt/scanner.log -- the hands-on agent confirmed
    live on crt-vm that a real scan's raw USB-keyboard keystrokes land in
    whichever tmux window has focus, but this window never read them, so
    scans silently did nothing. A background thread iterates sys.stdin
    (terminal cooked mode already buffers keystrokes until Enter) and feeds
    lines through a queue the main loop drains non-blockingly alongside the
    existing scanner.log tail -- parse_stdin_scan_line() validates the ISBN
    shape, then reuses handle_scan() unchanged.
    crt-console.sh now makes `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
2026-07-21 Add Book Game training-data stats + a secretary playbook for it
    bin/crt-book-game-stats.py: pure local summarizer (zero Claude calls) of
    books.db + book-game-training.jsonl -- book count, question-source mix,
    and STT accuracy (given top billing over trivia correctness, since
    that's the actual end-goal per .claude/FOCUS.md's 2026-07-21 statement:
    this whole subsystem exists to produce STT training data, not just play
    trivia). screen/print-all modes match crt-present-morning-report.py's
    existing convention.
    Wired into crt-secretary.py as a new book_game_stats playbook ("how's
    the book game going", "trivia stats") so progress is reachable by voice
    the same locally-answered way status/morning_r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
2026-07-21 Book Game answer grading: announce the result in-character
    grade_pending_answer() now includes the book's title; a new
    format_result_line() composes an actual game-show-host announcement
    (content/settled "got it!" for correct, clipped "nope, it was X" for
    wrong, neutral "logged your answer" for ungradeable fallback questions)
    in BOOK-GAME-STYLE.md's established register, instead of the previous
    raw debug-only print. Appended to ~/.crt/thoughts.log -- same channel
    crt-monologue.sh already tails -- so a graded spoken answer now actually
    surfaces on screen.
    6 new tests, 19 total in tests/test_book_answer_listen.py, full suite
    green.
2026-07-21 Build the speculative/optimistic-response filler (PARKING-LOT.md v1)
    bin/crt-speculate.py: pick_filler_line() -- a random warm/curious-
    register instant acknowledgment ("let me think on that...", "one sec,
    working on it..."), zero content prediction, zero API cost. v1
    simplification vs. the original sketch's per-category fillers: variety
    alone avoids the single-canned-phrase problem, category buckets are a
    fine follow-up not a requirement.
    Wired into crt-secretary.py's Claude-escalation path only (handle()'s
    fallthrough branch, via show_filler_line() -> crt-think.sh) -- never
    fires for a locally-answered playbook, since a filler for something
    that already answers instantly is pointless. Opt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
2026-07-21 Build v1 of voice-driven media playback (PARKING-LOT.md job #2)
    bin/crt-media-player.py: parse_media_command() is a pure natural-
    language parser (play/pause/resume/next/stop, "play the X"/"put on
    X"/"listen to X" prefixes) dispatching through a pluggable Backend --
    FakeBackend records calls for tests, VlcBackend sketches a real cvlc/
    media-library integration (never run against real audio hardware or
    files, swallows OSError throughout since neither exists in this
    sandbox).
    Wired into crt-secretary.py as a new `media` playbook, delegating match
    logic to parse_media_command() itself so the trigger definition can't
    drift between the two files.
    Found and flagged (not silently patched around)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
2026-07-21 crt-book-game-stats.py: export-fixups closes the STT-training loop
    New export-fixups mode converts repeated Book Game (expected, heard)
    mismatches into candidate bin/stt-fixups.json entries -- the exact
    shape that file already uses (STT-MECHANISM.md's garble taxonomy),
    always confidence:candidate (never confirmed -- that still needs a
    human calibration session, same bar the real file's existing entries
    were held to). Only surfaces a pair once it's recurred at least twice
    (tunable via min_repeats), since a one-off mismatch could just be noise.
    This is CLAUDE.md's top-priority "improve STT inference over time" loop
    actually closed end to end: scan -> question -> spoken answer -> logged
    mismat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
2026-07-21 Fix crash on unknown ISBN/network failure -- confirmed live, not theoretical
    fetch_book_metadata() raises on any ISBN Open Library doesn't recognize
    (confirmed live: curl against openlibrary.org/isbn/0000000000.json
    returns a real 404) or on a network failure, and nothing anywhere caught
    it. Since this feature's whole point is inviting someone to scan "any
    book nearby," this was guaranteed to crash the `book` window -- now the
    boot-default tmux window -- on a large fraction of real scans, not a
    rare edge case: out-of-print books, non-ISBN barcodes, a network hiccup.
    Same failure class as the earlier missing-random-import crash, just
    certain to recur constantly instead of being a one-off.
    cr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
2026-07-21 Fix books.db concurrency: WAL mode + retry on schema-init races
    books.db is no longer single-process -- crt-book-console.py,
    crt-book-answer-listen.py, crt-book-idle-bait.py,
    crt-book-game-stats.py, and the CLI can all open it concurrently now,
    but get_db() never enabled WAL mode (default rollback-journal mode
    blocks any reader while a writer holds the lock and vice versa).
    Fixed: get_db() now sets PRAGMA journal_mode=WAL and bumps the connect
    timeout to 10s. Writing a real 10-thread concurrent-writer stress test
    then caught a second, narrower race of its own: CREATE TABLE/ALTER
    TABLE can still transiently collide when several connections race to
    initialize a brand-new database file at the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
2026-07-21 Fix silent stdin-reader death (third bug from the happy-path audit)
    crt-book-console.py's stdin_reader() background thread -- the primary
    scan path now -- had a silent-failure mode: if sys.stdin ever hit EOF
    (e.g. the tmux pane's stdin gets closed/reattached) or raised any read
    error, the thread just died. The main loop kept running and looked
    perfectly healthy (idle/quote screens still rotating normally), but
    scanning via stdin quietly stopped working forever for the rest of that
    process's life, with zero visible indication -- same invisible-failure
    class as the unknown-ISBN crash and the sqlite concurrency bugs found
    in the last two passes, just in the input path this time.
    Fixed: stdin_r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
2026-07-21 Actually display the LCC call number on the CRT (resolved decision, never wired in)
    BOOK-GAME.md's roadmap step 4 resolved back on the vision day that
    label printing would be skipped for v1 in favor of "just display the
    computed LCC number on the CRT" -- but that decision was never actually
    implemented in crt-book-console.py. render_scan_result() now shows
    "Title (LCC)" in the question screen's title line when an LCC was
    computed, falling back to the plain title otherwise.
    In practice this often won't show anything extra: confirmed live that
    Open Library's ISBN endpoint rarely includes `subjects` (that's mainly
    on the Works endpoint), so compute_lcc frequently has nothing to work
    with -- a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
